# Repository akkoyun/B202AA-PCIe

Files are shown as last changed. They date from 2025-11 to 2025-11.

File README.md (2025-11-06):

# B202AA-PCIe  
### 3-Phase Energy Analyzer Module  
**Project:** PollyPhase Energy Analyzer  
**Author:** Mehmet Günce Akkoyun  
**Version:** 02.00.01  
**Date:** 06.11.2025  

---

## Overview  

**B202AA-PCIe** is a high-precision **three-phase energy analyzer module** designed for industrial and agricultural environments.  
The module is built around the **MAX78630+PPM/D00** poly-phase metering SoC and interfaces to the host system through a **custom PCIe-compatible connector**.  

It performs real-time measurement of:
- Line-to-neutral and line-to-line **voltages (VR, VS, VT)**  
- Phase currents via external **Current Transformers (CTs)**  
- Derived parameters such as **active/reactive/apparent power**, **energy (Wh)**, **power factor**, and **frequency**

The design focuses on:
- **High accuracy (Class 0.2S)** metering  
- **Complete galvanic isolation** for UART and alarm interfaces  
- **Wide input range and fault tolerance** for rugged field applications  

---

## Functional Blocks  

| Block | Function | Key Components |
|---|---|---|
| Voltage Input | Phase voltage scaling & isolation | 3×(3.3 M? + 1 k? divider, 22 nF filter, opto-isolator VOM617A) |
| Current Input | CT burden and protection | 3×(24.9 ? ± 0.1 % + 10 ? series, BAS316 clamps, 470 pF filter) |
| Measurement Core | 3-Phase metering | MAX78630+PPM/D00 |
| Isolation | UART & Alarm isolation | ISOW7821FDWE (UART), TLP2362 (AL1/AL2) |
| Power Isolation | 3.3 V - 3.3 V ISO DC/DC | PBT01F03S3V3 |
| Connector | Custom PCIe-style 52-pin edge | Compatible with all S-Bus PCIe modules |

---

## Measurement Inputs  

| Parameter | Nominal | Max (Continuous) | Description |
|---|---|---|---|
| Voltage (Phase–Neutral) | 230 V RMS | 400 V RMS | AC measurement via precision divider |
| Voltage (Phase–Phase) | 400 V RMS | 584 V RMS (safety) | Tested to 825 Vpk isolation |
| Current (CT input) | 5 A RMS nominal | 7 A RMS max | External CT, burden 24.9 ? + 10 ? |
| Frequency | 45 – 65 Hz | – | Automatic zero-cross detect |

---

## Electrical & Safety Specifications  

| Feature | Value / Description |
|---|---|
| **Galvanic Isolation** | ? 6 mm creepage/clearance (IPC9592 compliant) |
| **UART Isolation Voltage** | 2500 Vrms (ISOW7821) |
| **Alarm Isolation Voltage** | 3750 Vrms (TLP2362) |
| **TVS Protection** | 440 V (SMAJ440A) per phase |
| **Operating Temperature** | –25 °C to +85 °C |
| **Supply Voltage** | 3.3 V / 3.3 V ISO |
| **Power Consumption** | ? 0.8 W total |

---

## Accuracy & Error Budget  

### Voltage Channel (per phase)
| Item | Value | Note |
|---|---|---|
| Divider ratio | 3.3 M? : 1 k? | 0.1 % tolerance |
| Gain error (uncalibrated) | ±0.20 % | RSS of divider & ADC |
| Phase error (50 Hz) | –0.40° | From 22 nF filter |
| Gain drift (0–70 °C) | ±0.18 % | Typical |
| After calibration | ±0.05 % gain / ±0.05° phase | with 2-point + phase comp |

### Current Channel (per phase)
| Item | Value | Note |
|---|---|---|
| Burden | 24.9 ? ± 0.1 % + 10 ? | Kelvin connection |
| Gain error (uncalibrated) | ±0.20 % | ADC + burden |
| CT class impact | ±0.2 % – ±1.0 % | per CT rating |
| After calibration | ±0.10 – 0.20 % | typical |

### Combined Power (Active Power Error)
| Condition | PF = 1.0 | PF = 0.9 | PF = 0.5 |
|---|---|---|---|
| Uncalibrated (CT = 0.5 %) | ±0.58 % | ±0.67 % | ±1.34 % |
| Calibrated | ±0.10 – 0.20 % | ±0.15 – 0.25 % | ±0.20 – 0.35 % |

**Energy (Wh) Accuracy:**  
Limited by power error + timebase tolerance (20 MHz ± 50 ppm).  
Resulting energy error typically **< ±0.25 % over 24 h** integration.

---

## Safety Margin Calculations  

### Voltage Divider  
- Total resistance: 3.301 M?  
- At 230 Vac: I ? 0.32 mA › P_total = 0.073 W  
- At 400 Vac: I ? 0.56 mA › P_total = 0.22 W  
- Per resistor (180 k?): ? 56 mW / 0.5 W = 11 % load  
- Temperature rise ? +14 °C › **safe below 74 °C**

### CT Burden Protection  
- Normal V_burden ? 0.25 Vpk (5 A RMS)  
- Clamp limit ? ±0.7 V › 3× margin  
- Diodes conduct only under fault, ensuring **no influence on phase**.

### Isolation  
- Creepage/clearance: ? 6 mm  
- TVS breakdown: 440 V pk  
- Withstand: 2.5 kVrms (UART) / 3.75 kVrms (Alarm)  

---

## Performance Summary  

| Parameter | Result |
|---|---|
| Voltage Accuracy | ±0.05 % (calibrated) |
| Current Accuracy | ±0.10 – 0.20 % (CT dependent) |
| Active Power Accuracy | ±0.20 – 0.35 % (typical PF range) |
| Energy Accuracy | ±0.25 % / day |
| Phase Drift | ? 0.05° (after compensation) |
| Temperature Coefficient | < 0.02 % / °C |
| Safety Margin (400 V RMS) | +45 % |

---

## Subsystem Scores  

| Subsystem | Score (10) | Notes |
|---|---|---|
| Phase Sense / Opto Isolation | **9.5** | Excellent thermal and fault safety |
| Voltage Divider & Filter | **9.0** | Very accurate; phase comp suggested |
| CT Channel & Protection | **9.5** | Ideal burden use, safe clamp |
| UART Isolation | **9.0** | Layout decoupling critical |
| Alarm Isolation | **9.0** | LED logic verified, add 100 ? ESD resistor |
| MAX78630 Core Integration | **9.5** | Datasheet-accurate, stable design |
| Power & EMC Architecture | **9.0** | Add CMC for field noise immunity |
| Connector & System Integration | **9.0** | Solid mechanical & logical design |

**Overall Design Score:** ? **9.2 / 10**

---

## Calibration & Testing  

**Recommended Calibration Steps:**  
1. Two-point voltage and current gain calibration (0.5 FS & FS).  
2. Phase compensation per channel at 50 Hz reference.  
3. Optional temperature drift mapping (25 °C / 50 °C / 70 °C).  
4. Verify PF = 1.0 and PF = 0.5 energy accumulation error.  

**Expected Post-Calibration Class:**  
- **Class 0.2 / 0.2S** accuracy (EN 62053-22 compliant).

---

## Licensing & Documentation  

© 2025 Günce Akkoyun – All Rights Reserved  
Design and documentation by **Mehmet Günce Akkoyun**  
Commercial use without permission is prohibited.  

**Repository:** [github.com/akkoyun/B202AA-PCIe](https://github.com/akkoyun/B202AA-PCIe)  
**Contact:** akkoyun@me.com  

---

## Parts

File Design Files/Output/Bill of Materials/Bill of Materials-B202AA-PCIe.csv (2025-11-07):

ROHS | Designator | Manufacturer Name | Manufacturer Part Number | Quantity | Case | Description | Max Input Voltage | Max Operating Temperature | Tolerance | Value | Product Type
 | C1, C4, C11, C14, C21, C22, C23, C25, C26 | AVX, KYOCERA AVX | 04026D104KAT4A | 9 | 0402 | Capacitor - 100nF [0402-6V3] (Ceramic), Capacitor (MLCC) - 100nF / 6V3 / 0402 |  |  | %10 | 100nF
 | C2, C5, C24, C27 | Murata Electronics | GRM153R60J105ME95D | 4 | 0402 | Capacitor (MLCC) - 1uF / 6V3 / 0402 |  |  | 20% | 1uF
 | C3, C6 | KYOCERA AVX | 04026D473KAT2A | 2 | 0402 | Capacitor (MLCC) - 47nF / 6V3 / 0402 |  |  | 10% | 47nF
 | C7, C8, C9 | Murata | GRM1885C1H471JA01 | 3 | 0603 | Capacitor (MLCC) - 470pF / 50V / 0603 |  |  | 5% | 470pF
 | C10 | Murata Electronics | GCJ188R71E105KA01D | 1 | 0603 | Capacitor (MLCC) - 1uF / 25V / 0603 |  |  | 10% | 1uF
 | C12, C13 | KYOCERA AVX | 04025A8R0CAT2A | 2 | 0402 | Capacitor - 8pF [0402] (Ceramic) |  |  | 0.25pF | 8pF
 | C15, C16, C17 | Yageo | C0805C223K5RACTU | 3 | 0805 | Capacitor (MLCC) - 22nF / 50V / 0805 |  |  | 10% | 22nF
 | C18, C19, C20 | Murata | GRM155R71H102KA01D | 3 | 0402 | Capacitor (MLCC) - 1nF / 50V / 0402 |  |  | 10% | 1nF
 | C28 | KEMET | C0402C475M9PACTU | 1 | 0402 | Multilayer Ceramic Capacitors - SMD - 6V3 4.7uF X5R 0402 20% |  |  | 20% | 4.7uF
 | C29 | Wurth Elektronik | 885012207024 | 1 | 0805 | Multilayer Ceramic Capacitors MLCC - SMD/SMT WCAP-CSGP 2.2uF 0805 10% 10V MLCC |  |  | 10% | 2.2uF
Yes | D1, D2, D9, D13, D17 | ROHM Semiconductor | SML-P12VTT86R | 5 | 0402 | Standard LEDs - SMD MINI-MOLD ULTRA COMPACT RED
Yes | D3, D4, D5, D6, D7, D8 | Panjit | BAS316_R1 | 6 | SOD-323-2 | Small Signal Switching Diodes 100V,Small Signal Switching Diodes,SOD-323,4A |  |  |  |  | Small Signal Switching Diodes
Yes | D10, D12, D14 | Nexperia | BZT52H-B5V1,115 | 3 | SOD-123F-2 | Zener Diodes BZT52H-B5V1/SOD123F/SOD2 |  |  |  |  | Zener Diodes
Yes | D11, D15, D19 | Bourns | SMAJ440A | 3 | DO-214AC-2 | ESD Protection Diodes / TVS Diodes 440volts 1uA .6 Amps Uni-Dir |  |  |  |  | TVS Diodes
 | FB1 | Murata Electronics | BLM18EG101TZ1D | 1 | 0603 | Ferrite Beads 0603 100ohms 2000mA Auto Infotainment |  |  | 25% | BLM18EG101TZ1D
 | J2 | Molex | 53426-0710 | 1 | TH | 2.50mm Pitch Mini-Lock Wire-to-Board Header Right Angle Friction and Positive Lock 7 Circuits
Yes | J3 | Molex | 53261-0671 | 1 |  | Mini Tunic Connector with 6P
 | R1, R4, R49, R55, R61 | Vishay | CRCW04024K70FKED | 5 | 0402 | Thick Film Resistors - SMD 1/16 W 4.7 KOhm 1% |  |  | %1 | 4K7
 | R2, R5 | Vishay | CRCW04021K80FKED | 2 | 0402 | Thick Film Resistors - SMD 1/16 W 1.8 KOhm 1% |  |  | %1 | 1K8
 | R3, R6 | Vishay | CRCW040247R0FKED | 2 | 0402 | Thick Film Resistors - SMD 1/16 W 47 Ohm 1% |  |  | %1 | 47R
 | R7, R10, R13 | Yageo | RT0805BRD0710RL | 3 | 0805 | Thick Film Resistors - SMD 1/8 W 10 Ohm 0.1% |  |  | %0.1 | 10R
 | R8, R11, R14 | Yageo | RT1206BRD0724R9L | 3 | 1206 | Burden Resistors - SMD 1/4 W 24.9 Ohm 0.1% |  |  | 0.1% | 24R9
 | R9, R12, R15, R30 | Vishay | CRCW04020000Z0ED | 4 | 0402 | Thick Film Resistors - SMD 1/16 W 0 Ohm |  |  |  | 0R
 | R16, R17, R18, R19, R20, R21, R33, R75 | Vishay | CRCW040210K0FKED | 8 | 0402 | Thick Film Resistors - SMD 1/16 W 10 KOhm 1% |  |  | %1 | 10K
 | R22, R24, R26, R27, R28, R29, R31, R32, R67, R68, R69, R70 | Vishay | CRCW040247K0FKED | 12 | 0402 | Thick Film Resistors - SMD 1/16 W 47 KOhm 1% |  |  | %1 | 47K
 | R23, R25, R71, R72, R73, R74 | Vishay | CRCW040233R0FKED | 6 | 0402 | Thick Film Resistors - SMD 1/16 W 33 Ohm 1% |  |  | %1 | 33R
 | R34, R35, R36, R38, R39, R40, R42, R43, R44 | Yageo | RT1206BRD071M1L | 9 | 1206 | Thick Film Resistors - SMD 1/4 W 1.1 MOhm 0.1% |  |  | %0.1 | 1M1
 | R37, R41, R45 | Vishay | CRCW0805100RFKEA | 3 | 0805 | Thick Film Resistors - SMD 1/4 W 100 Ohm 1% |  |  | %1 | 100R
 | R46, R47, R48 | Panasonic | ERA-6AEB102V | 3 | 0805 | Thick Film Resistors - SMD 1/8 W 1 KOhm 0.1% |  |  | %0.1 | 1K
 | R50, R56, R62 | Vishay | CRCW0402100KFKED | 3 | 0402 | Thick Film Resistors - SMD 1/16 W 100 KOhm 1% |  |  | %1 | 100K
 | R51, R52, R53, R54, R57, R58, R59, R60, R63, R64, R65, R66 | Panasonic | ERJ-P06D1803V | 12 | 0805 | Thick Film Resistors - SMD 0805 180Kohms 0.5W 0.5% AEC-Q200 |  |  | %0.5 | 180K
 | U1, U2 | Toshiba | TLP2362(TPR,E | 2 | SMD | High Speed Optocouplers 3750 Vrms 10MBd 4mA 2.7 to 5.5V LED
Yes | U3 | Silergy | MAX78630+PPM/D00 | 1 | TQFN-32 | Energy Measurement Processor 32-Pin TQFN EP Tube
Yes | U4, U5, U6 | Vishay | VOM617A-4T | 3 | SOP-4 | Transistor Output Optocouplers Phototransistor Out CTR 160-320% 5mA |  |  |  |  | Transistor Output Optocouplers
 | U7 | Texas Instruments | ISOW7821FDWE | 1 | SOIC-16 | Digital Isolators Dual-channel 1/1 r einforced digital is A 595-ISOW7821FDWER
 | U8, U9, U10 | OnSemi | MB10S | 3 | SOIC-4 | Transistor Output Optocouplers Optocplr Phototrans 4-Channel
 | X1 | Kyocera Electronic Components | CX2016DB20000D0GPSC1 | 1 | SMD | Crystals AEC-Q200 20000kHz 8pF 2x1.6mm

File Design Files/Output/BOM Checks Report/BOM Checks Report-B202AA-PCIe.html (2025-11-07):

Date: |  | 7.11.2025
Time: |  | 15:56
Elapsed Time: |  | 00:00:00
Filename: |  | C:\Users\akkoyun\Documents\B202AA-PCIe\Design Files\B202AA-PCIe.BomDoc
Warnings: |  | 14
Errors: |  | 0
Fatal Errors: |  | 135
Warnings: | Count
Value '100nF' is duplicate | 9
Value '1uF' is duplicate | 5
Total | 14
Errors: | Count
Total | 0
Fatal Errors: | Count
No solutions | 135
Total | 135
Value '100nF' is duplicate
C1 , C4, C11, C14, C21, C22, C23, C25, C26
Value '1uF' is duplicate
C2 , C5, C10, C24, C27
No solutions
C1 , C2, C3, C4, C5, C6, C7, C8, C9, C10, C11, C12, C13, C14, C15, C16, C17, C18, C19, C20, C21, C22, C23, C24, C25, C26, C27, C28, C29, D1, D2, D3, D4, D5, D6, D7, D8, D9, D10, D11, D12, D13, D14, D15, D17, D19, FB1, J2, J3, R1, R2, R3, R4, R5, R6, R7, R8, R9, R10, R11, R12, R13, R14, R15, R16, R17, R18, R19, R20, R21, R22, R23, R24, R25, R26, R27, R28, R29, R30, R31, R32, R33, R34, R35, R36, R37, R38, R39, R40, R41, R42, R43, R44, R45, R46, R47, R48, R49, R50, R51, R52, R53, R54, R55, R56, R57, R58, R59, R60, R61, R62, R63, R64, R65, R66, R67, R68, R69, R70, R71, R72, R73, R74, R75, U1, U2, U3, U4, U5, U6, U7, U8, U9, U10, X1

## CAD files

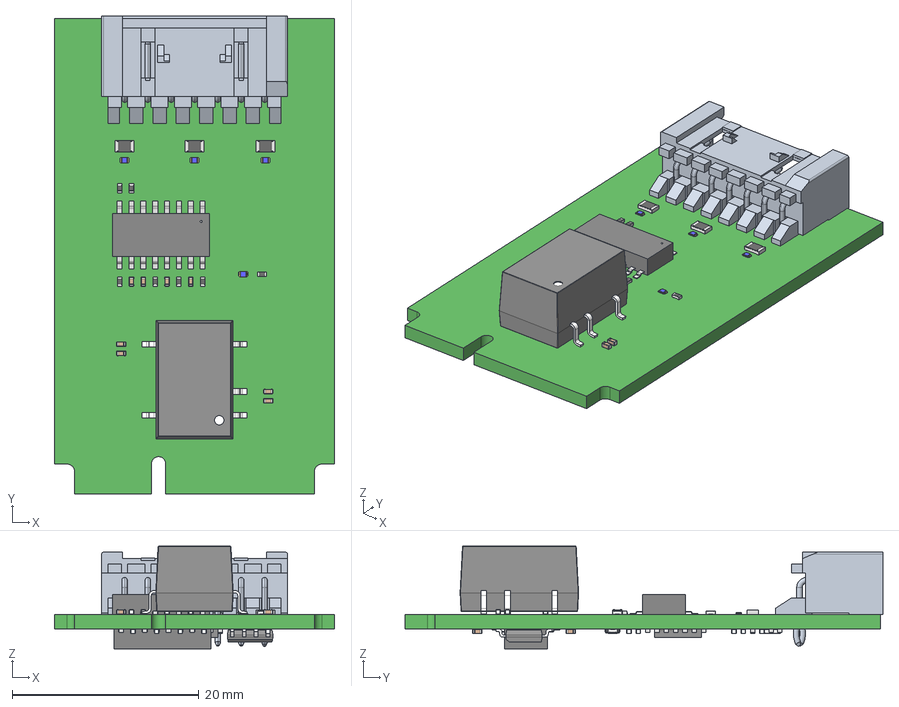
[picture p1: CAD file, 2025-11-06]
Design Files/Output/Export STEP/B202AA-PCIe.step
30.0 x 51.2 x 11.0 mm
SOP-16_TCMT_VIS x 2
0805CRCW x 6
0402CRCW x 42
User Library-LED_1006_B_Cut006 x 4
User Library-LED_1006_B_Cut005 x 4
User Library-LED_1006_B_Cut005_(Mirror_#1) x 4
User Library-LED_1006_B_Pad001 x 4
User Library-LED_1006_G_Gruen x 4
0402CAPMLCC x 33
ACIS Solid_1923
ACIS Solid_1935
SO8 Narrow 3.9mm x 9
QFN32 5x5
PDS1-S3-S3-M

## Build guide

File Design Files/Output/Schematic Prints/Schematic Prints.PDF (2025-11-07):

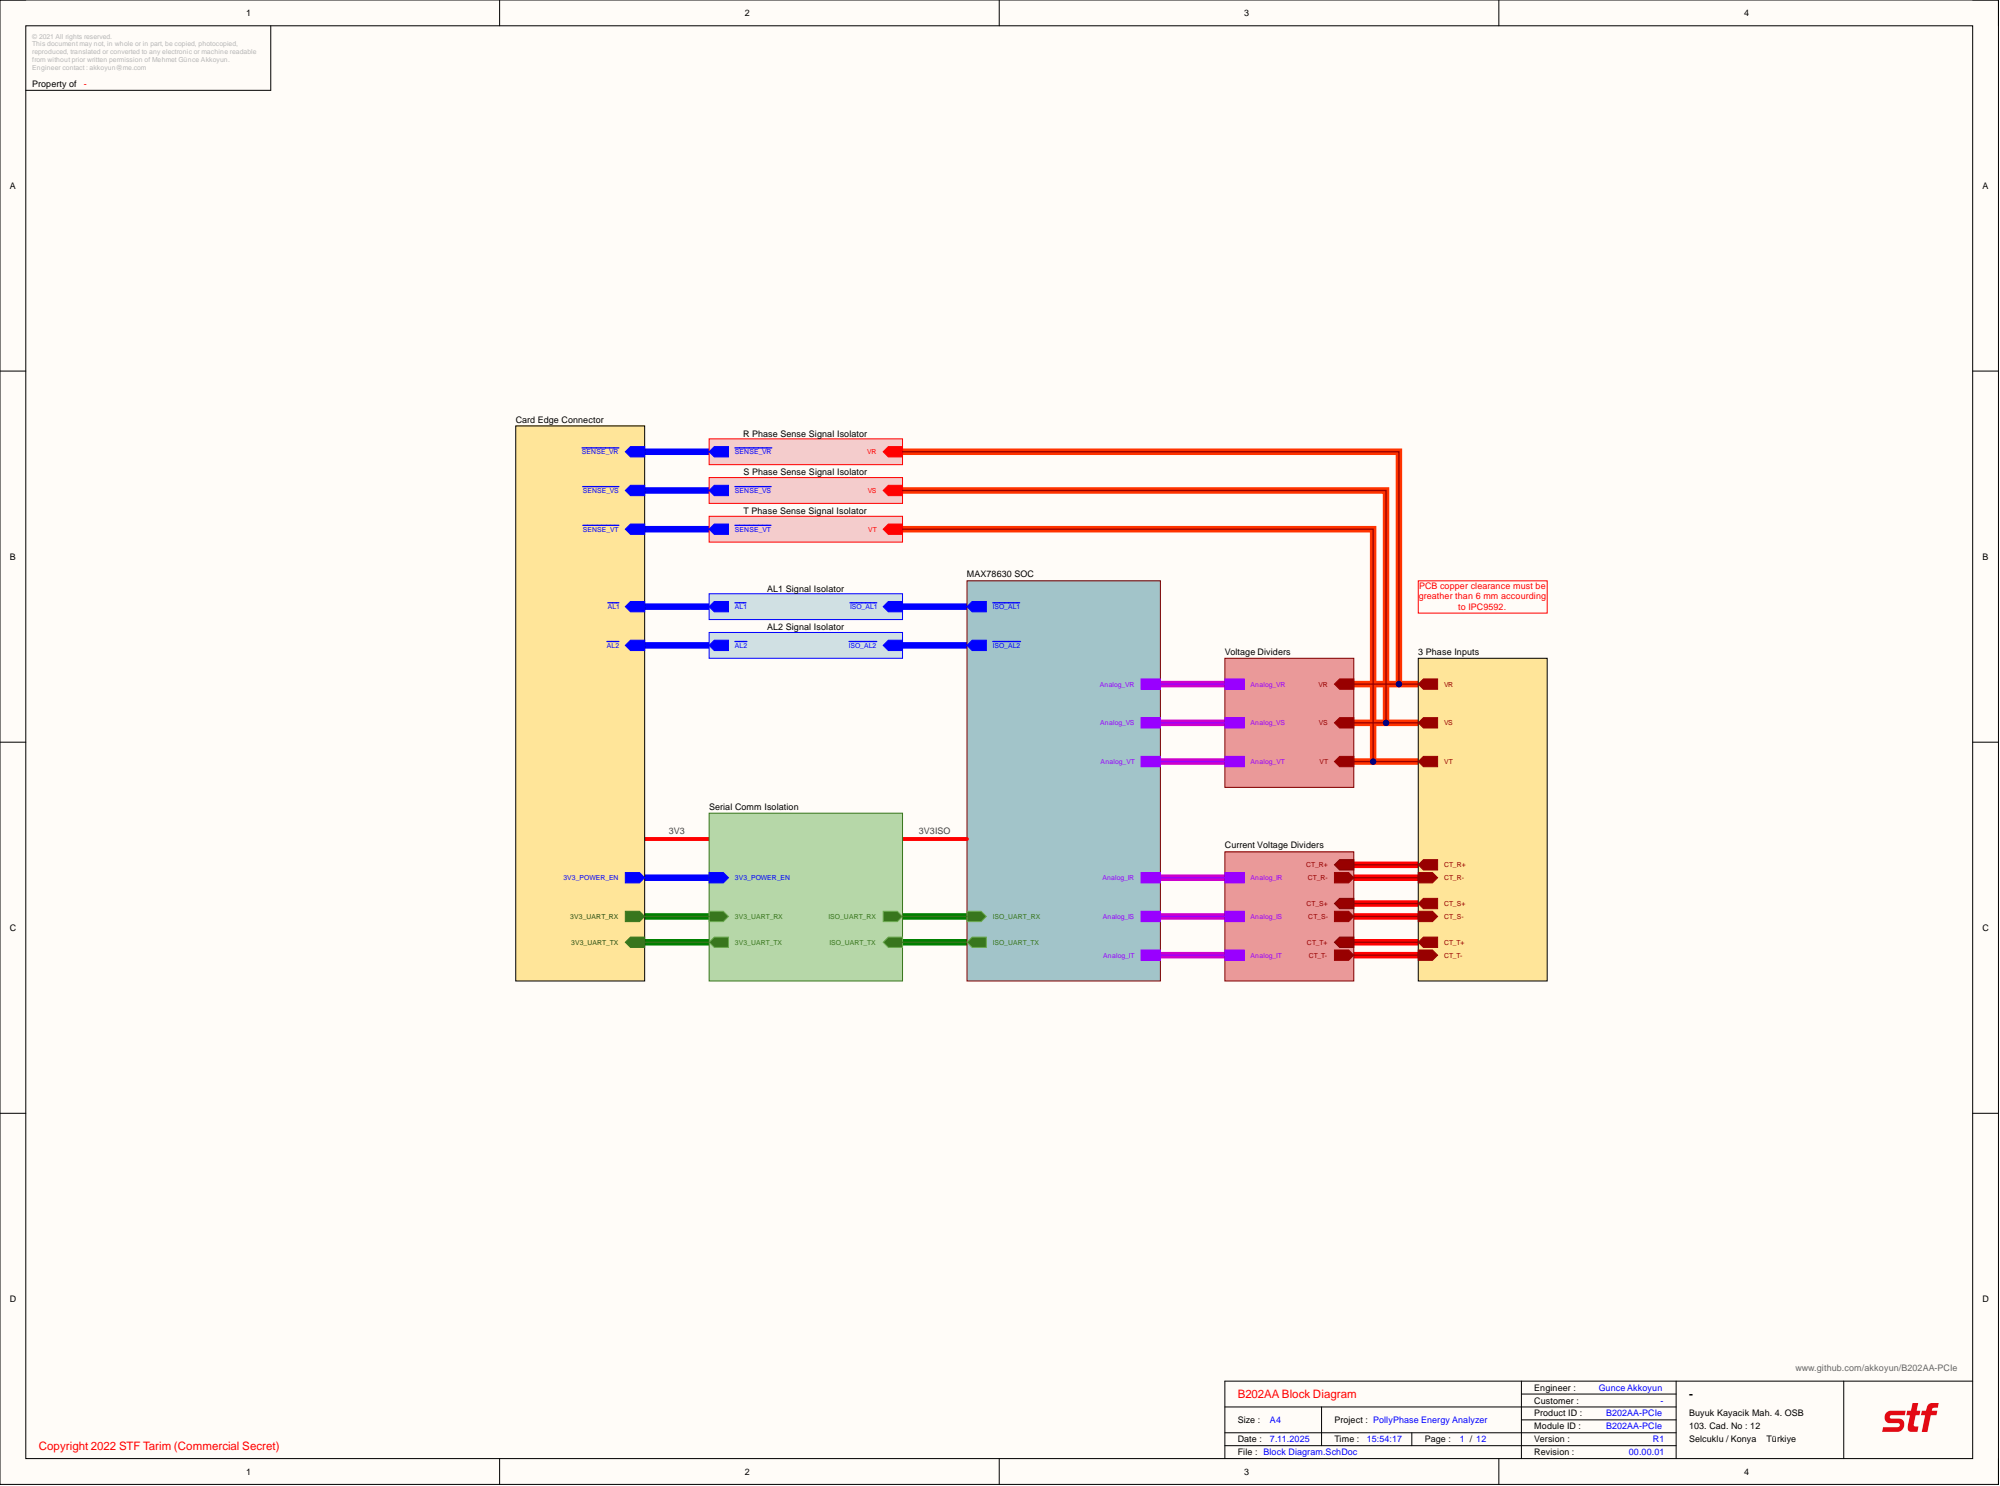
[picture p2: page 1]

© 2021 All rights reserved.
This document may not, in whole or in part, be copied, photocopied,
reproduced, translated or converted to any electronic or machine readable
from without prior written permission of Mehmet Günce Akkoyun.
Engineer contact : akkoyun@me.com

R Phase Sense Signal Isolator

S Phase Sense Signal Isolator

T Phase Sense Signal Isolator

PCB copper clearance must be
greather than 6 mm accourding

ISO_UART_TX

www.github.com/akkoyun/B202AA-PCIe

Buyuk Kayacik Mah. 4. OSB
103. Cad. No : 12
Selcuklu / Konya Türkiye

Copyright 2022 STF Tarim (Commercial Secret)

File : Block Diagram.SchDoc

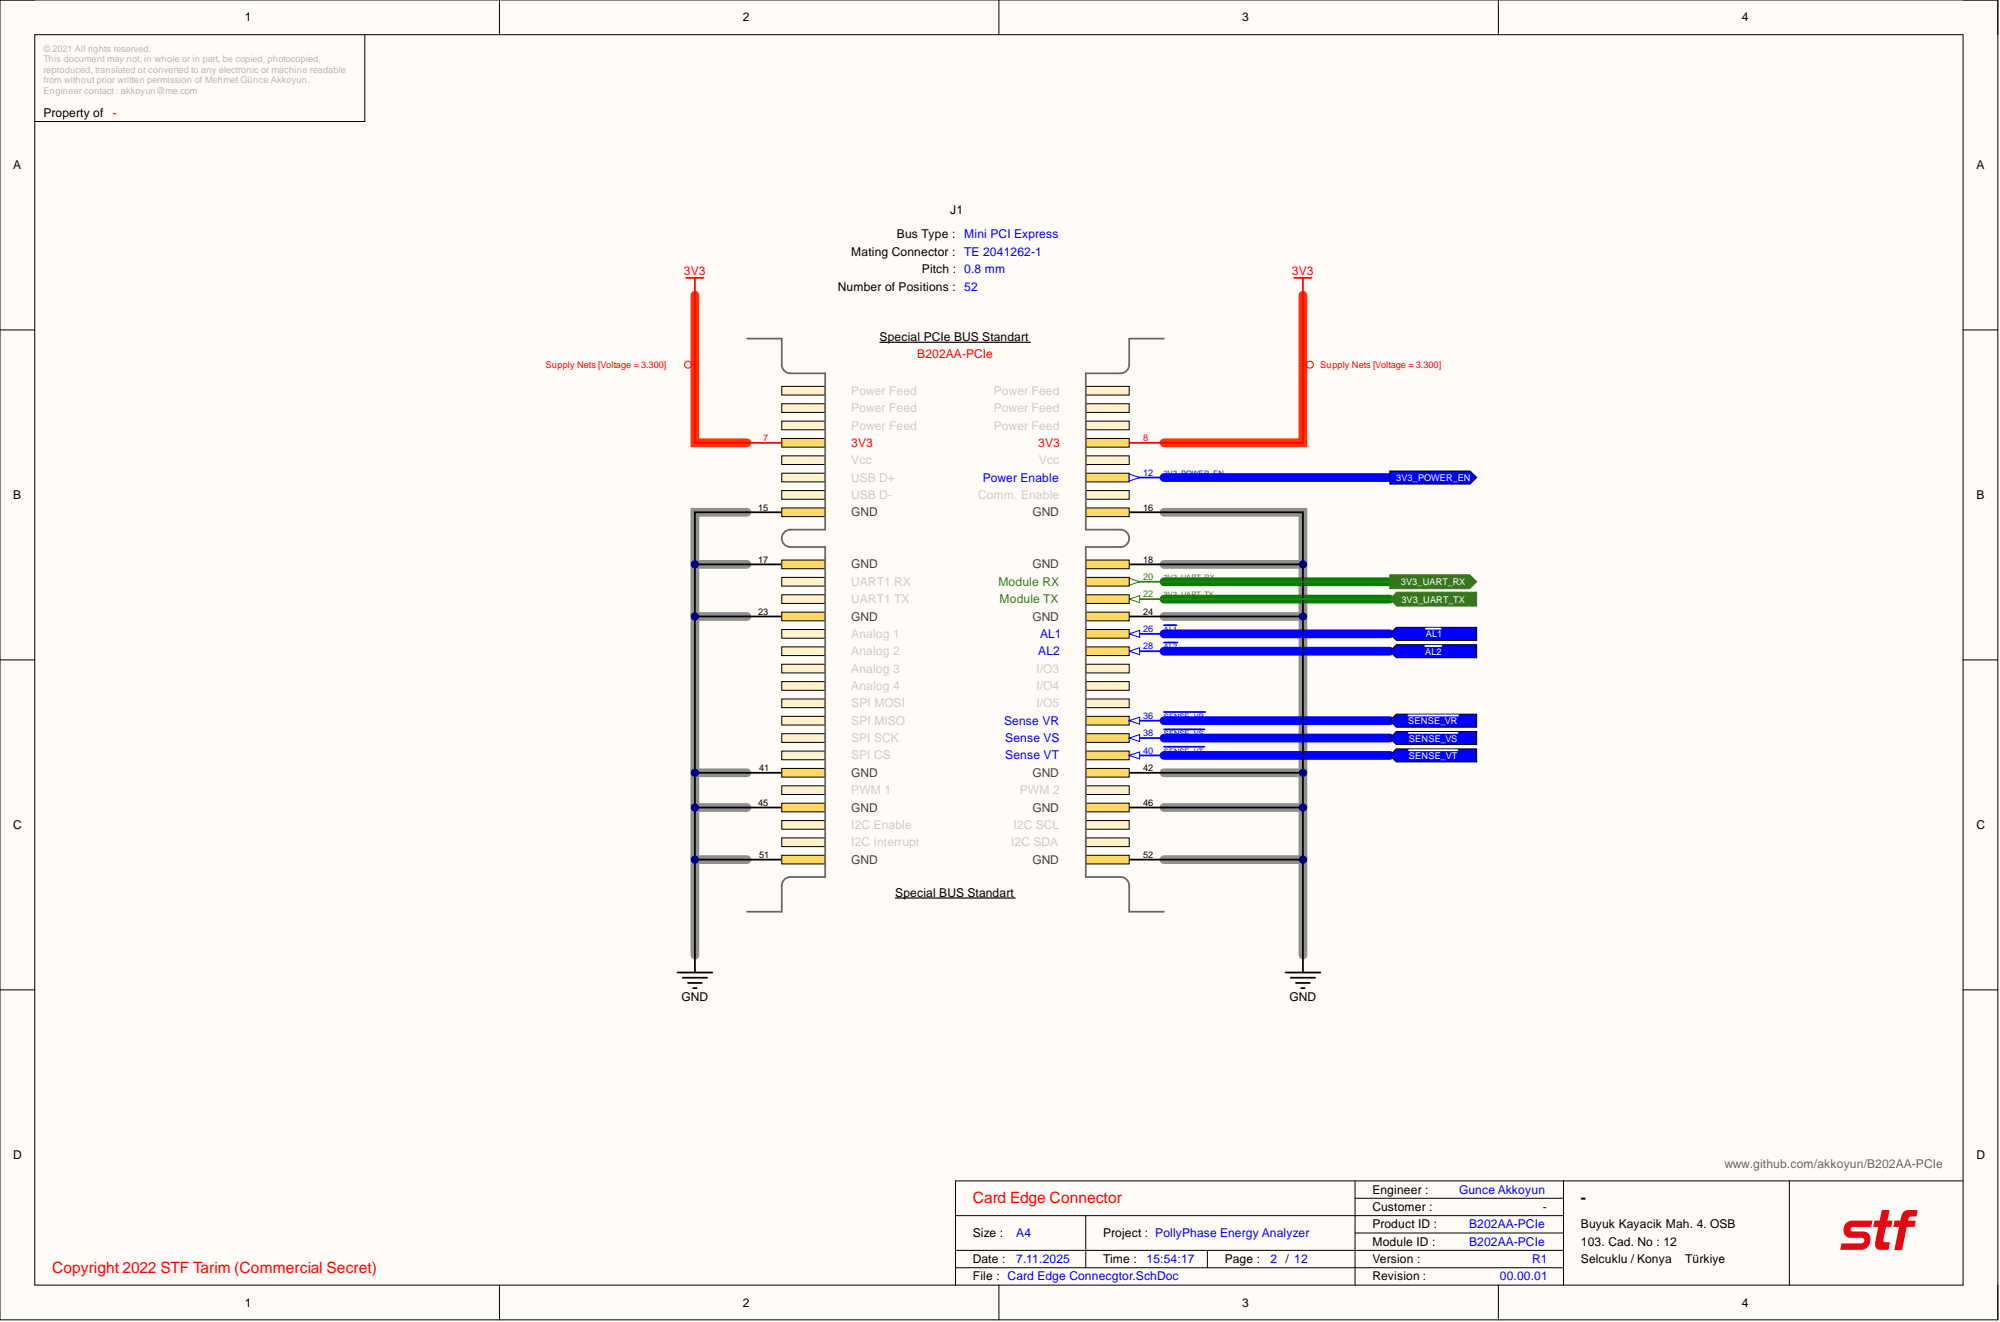
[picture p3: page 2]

Special PCIe BUS Standart

www.github.com/akkoyun/B202AA-PCIe

File : Card Edge Connecgtor.SchDoc

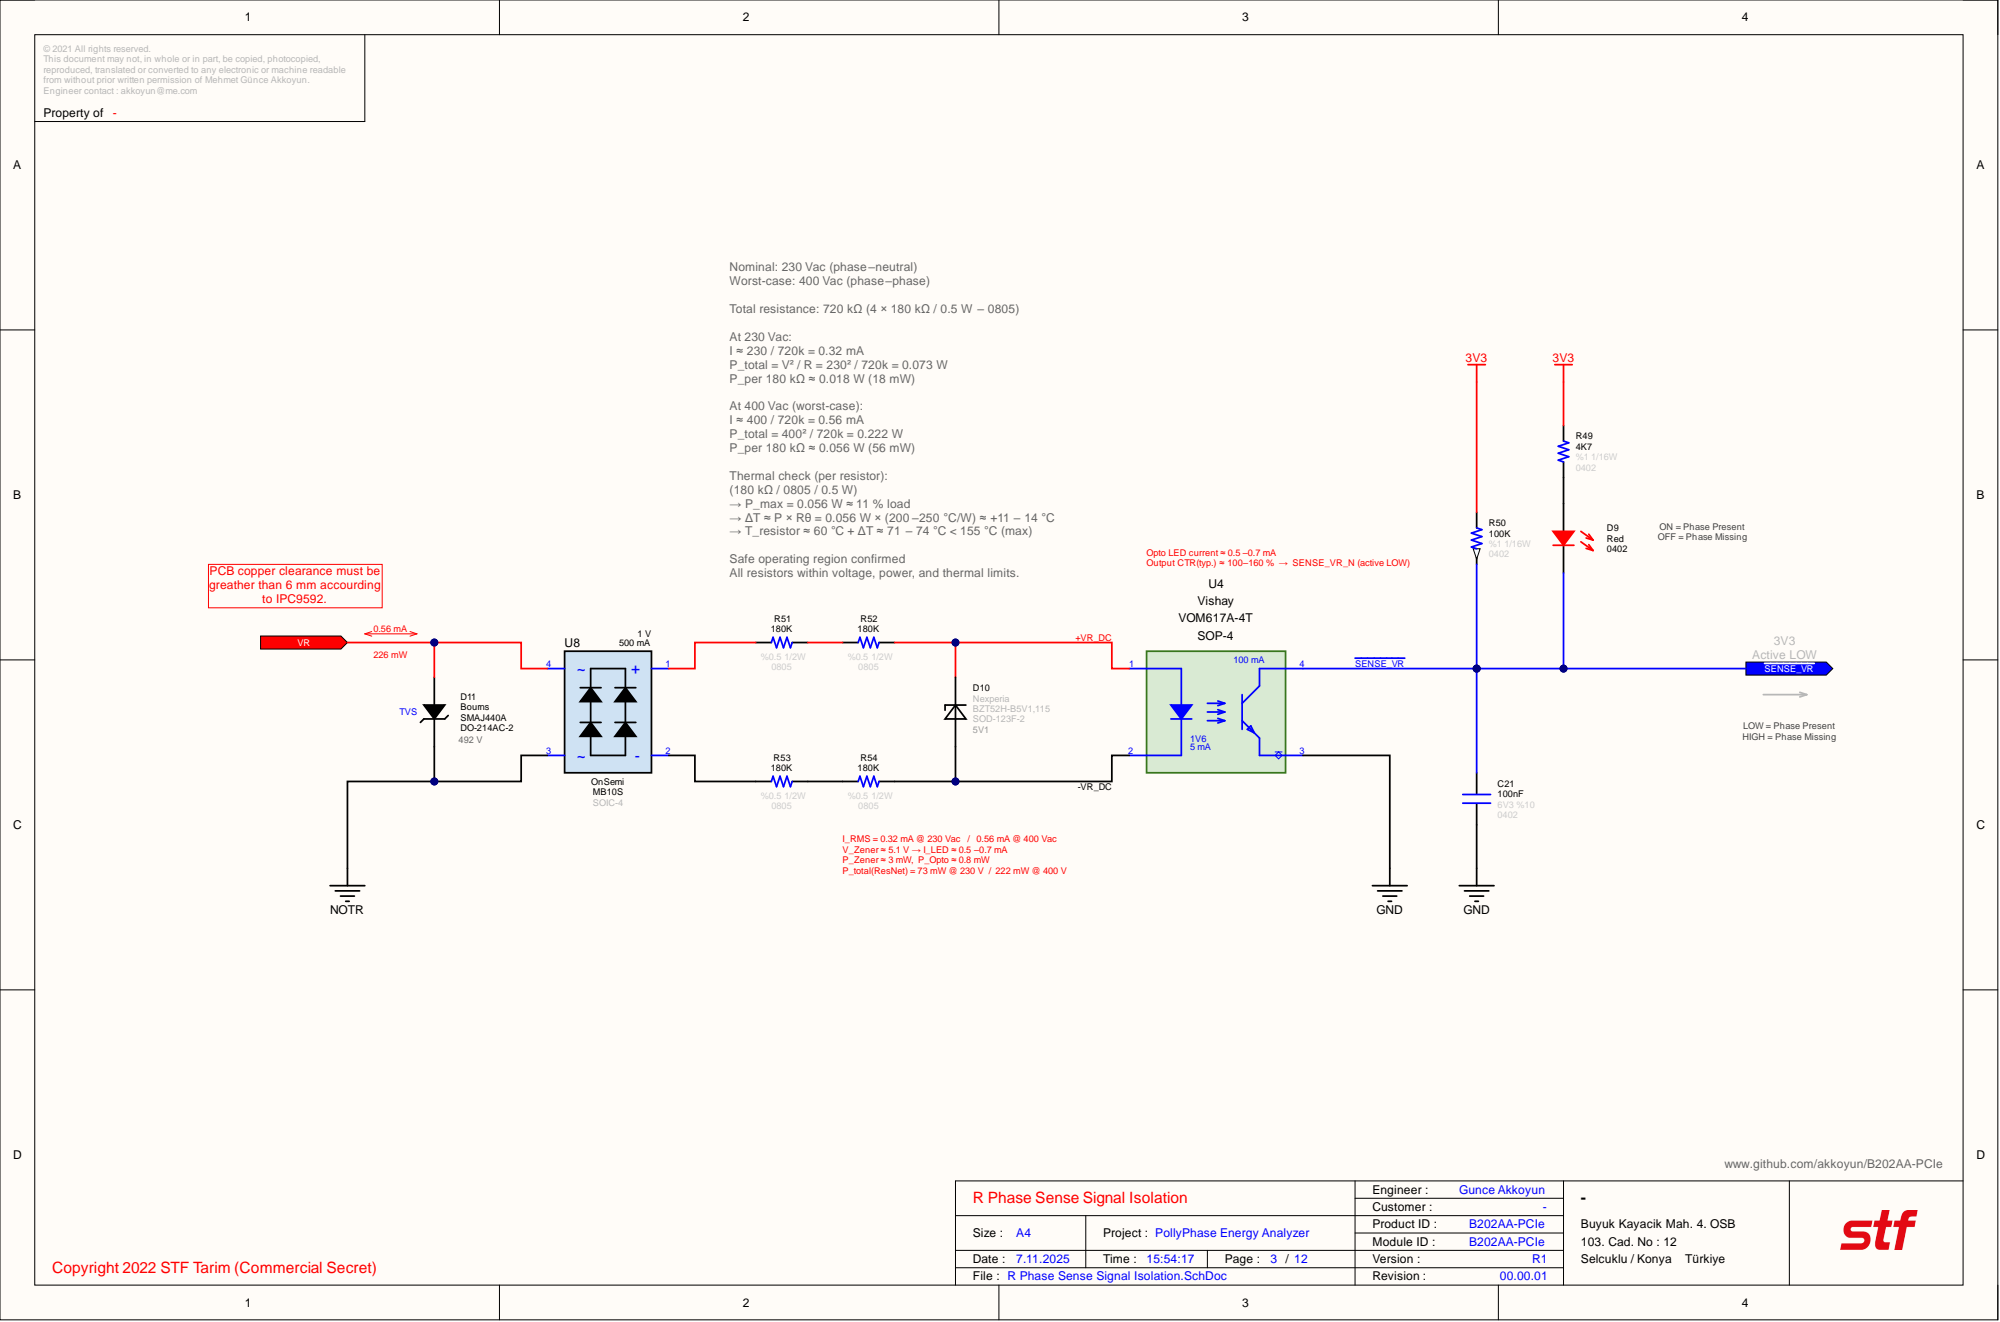
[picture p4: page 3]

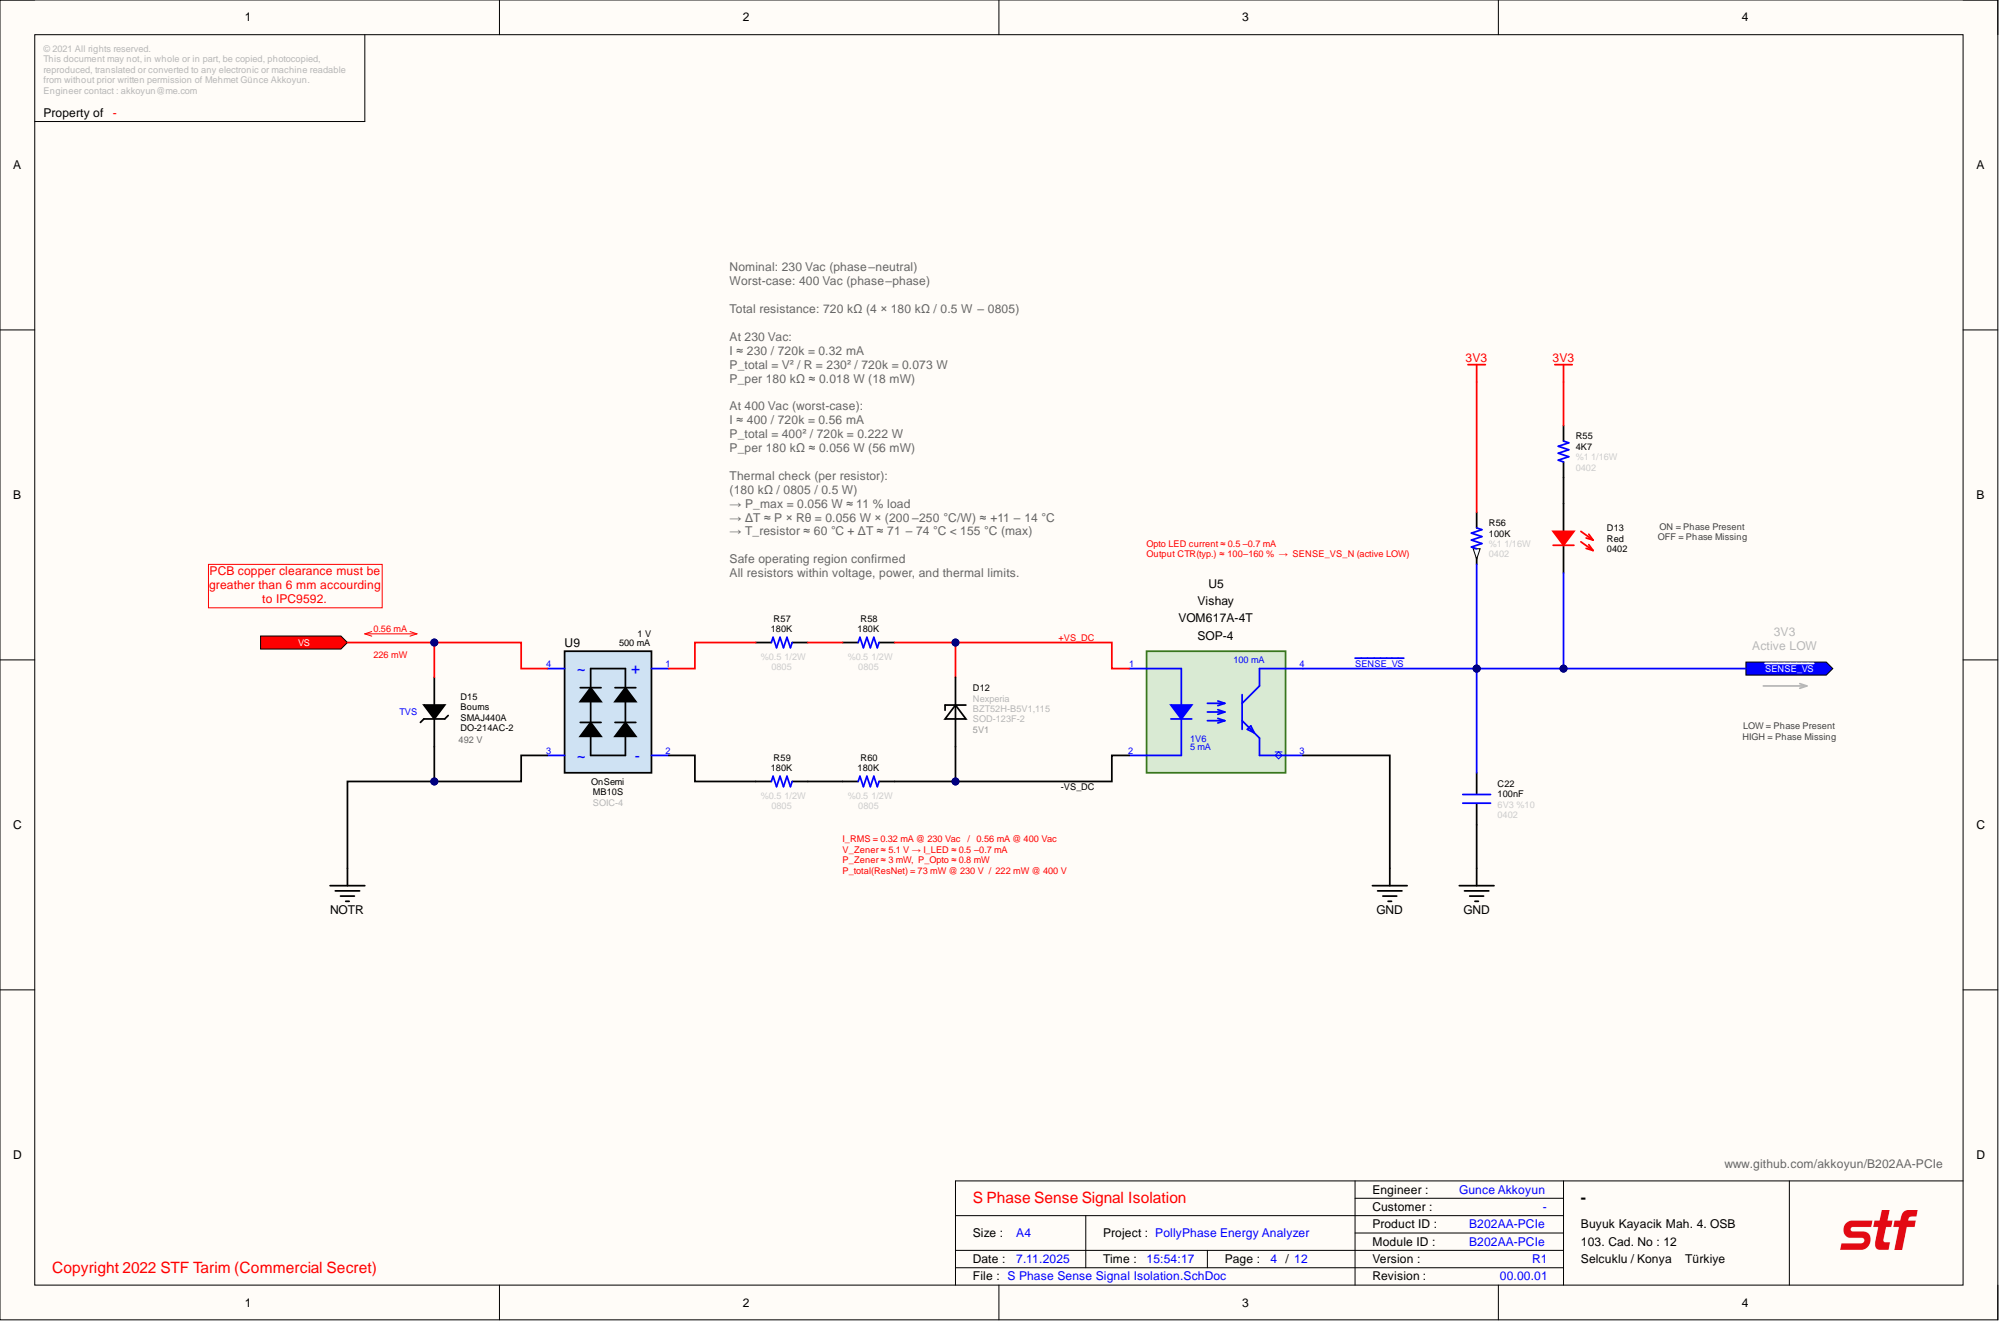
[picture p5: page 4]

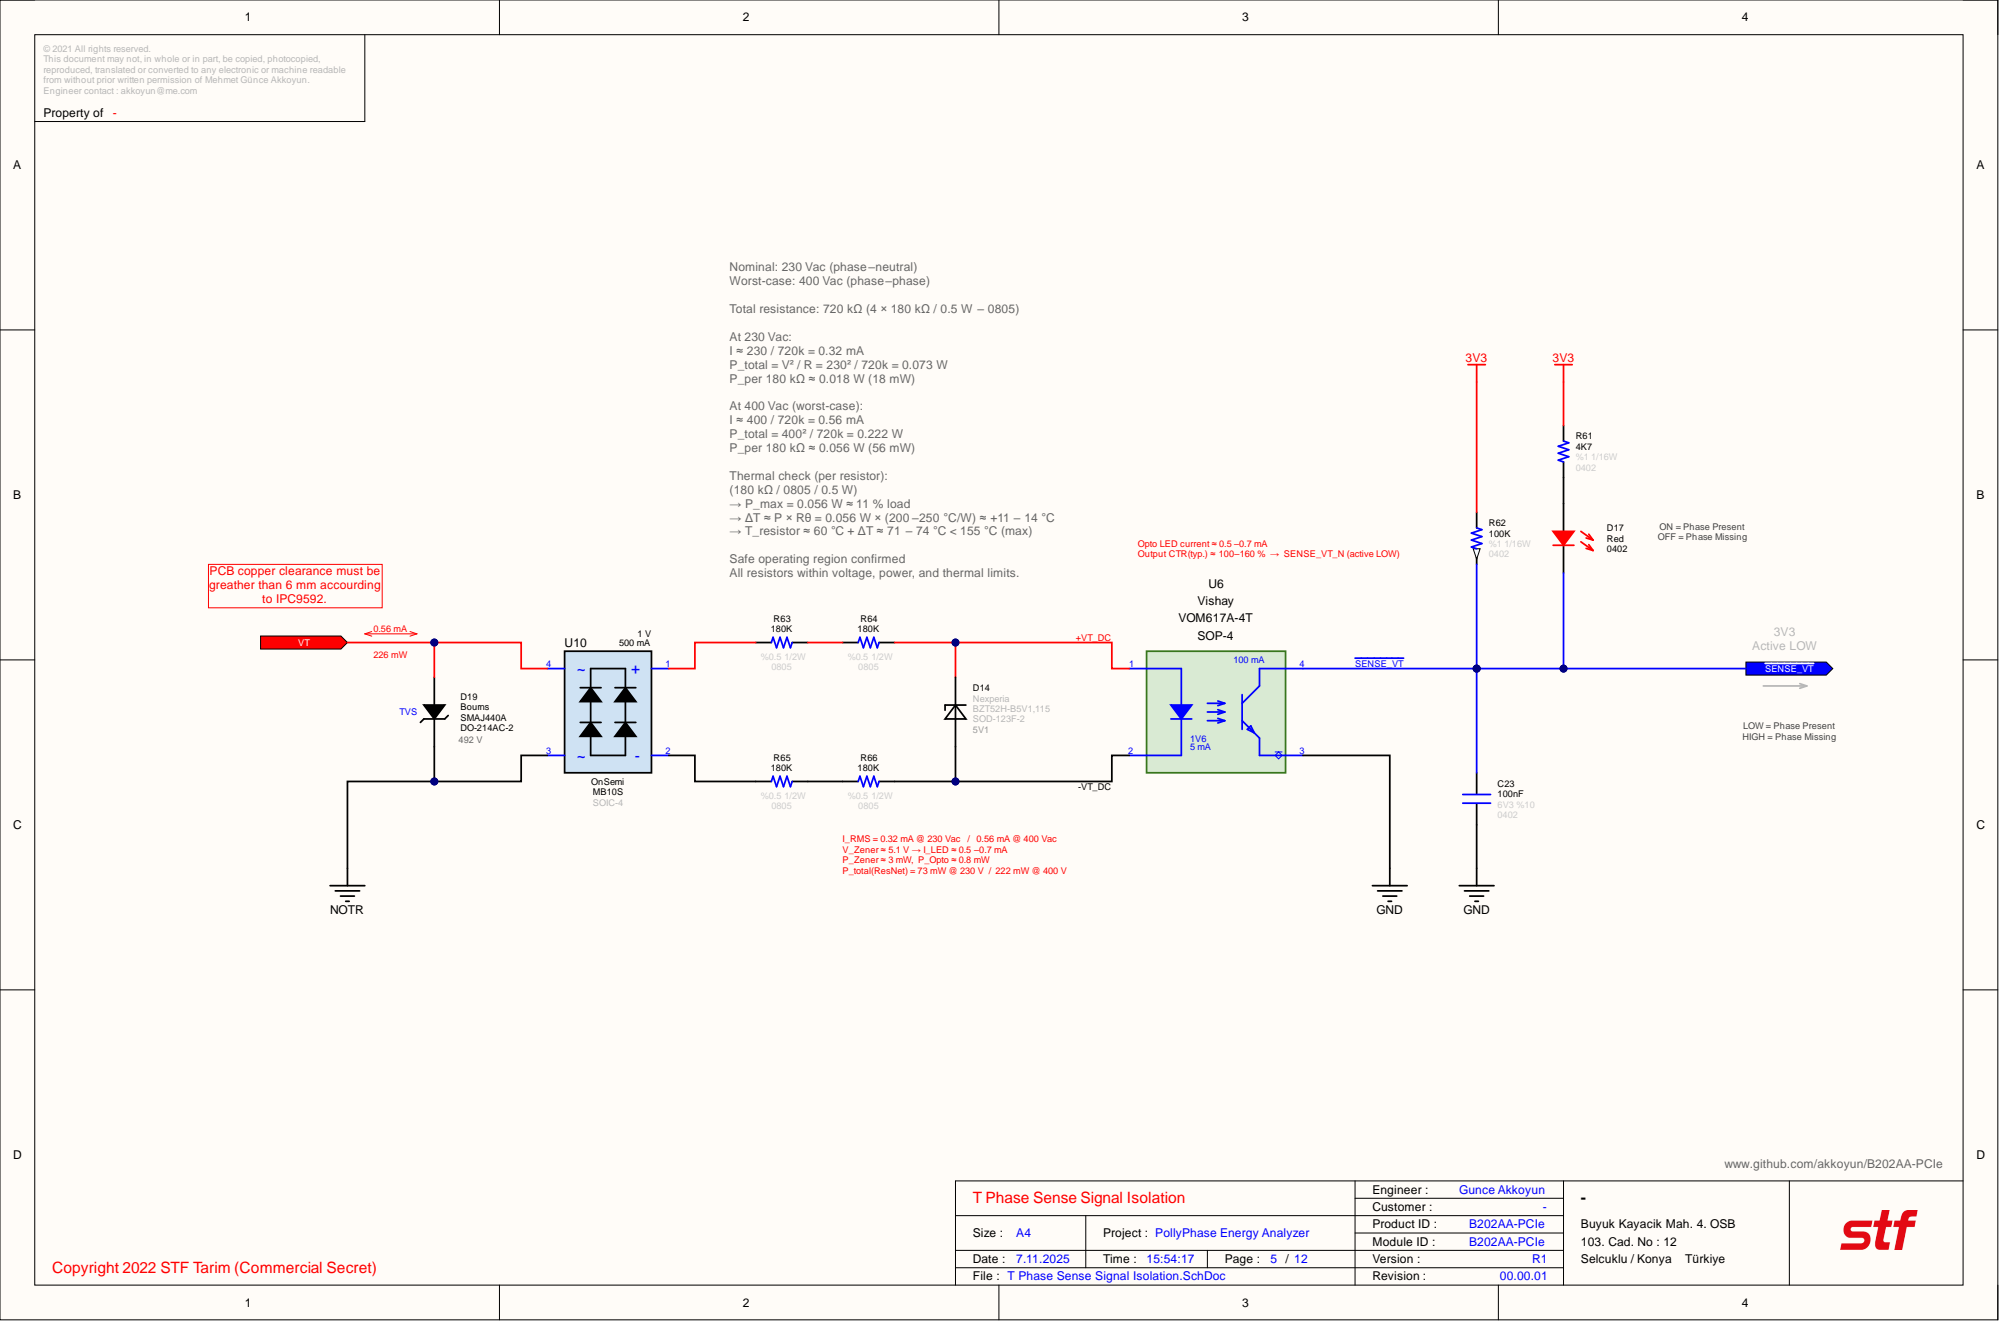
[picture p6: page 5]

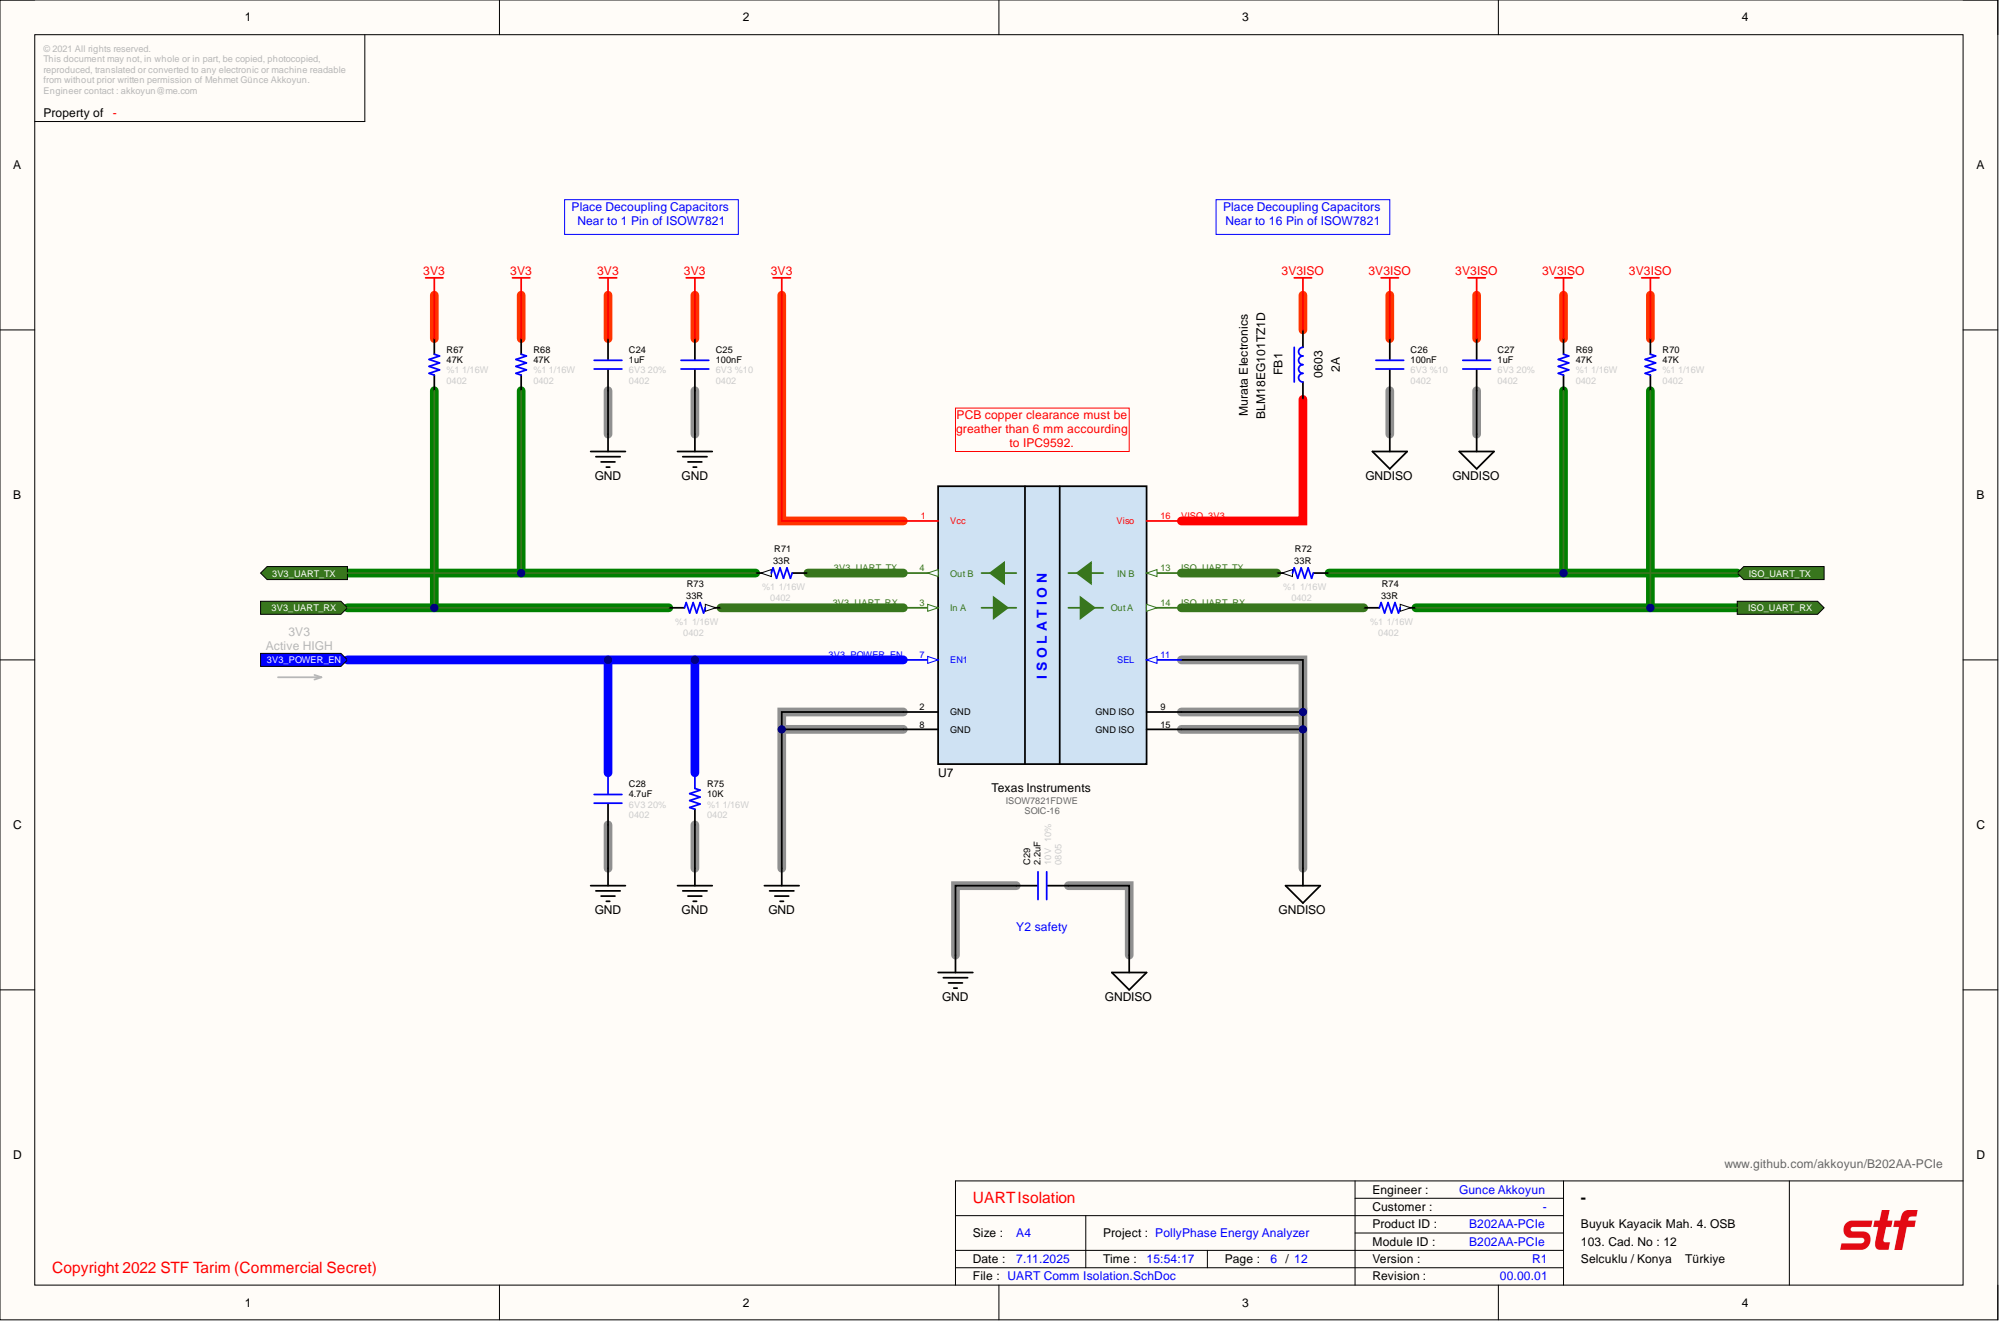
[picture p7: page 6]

Place Decoupling Capacitors
Near to 1 Pin of ISOW7821

Near to 16 Pin of ISOW7821

PCB copper clearance must be
greather than 6 mm accourding

Vcc 1 | GND ISO

Out B 4 In A 3 EN1 7 GND 2 | | ISO_UART_TX_

GND 8

www.github.com/akkoyun/B202AA-PCIe

File : UART Comm Isolation.SchDoc

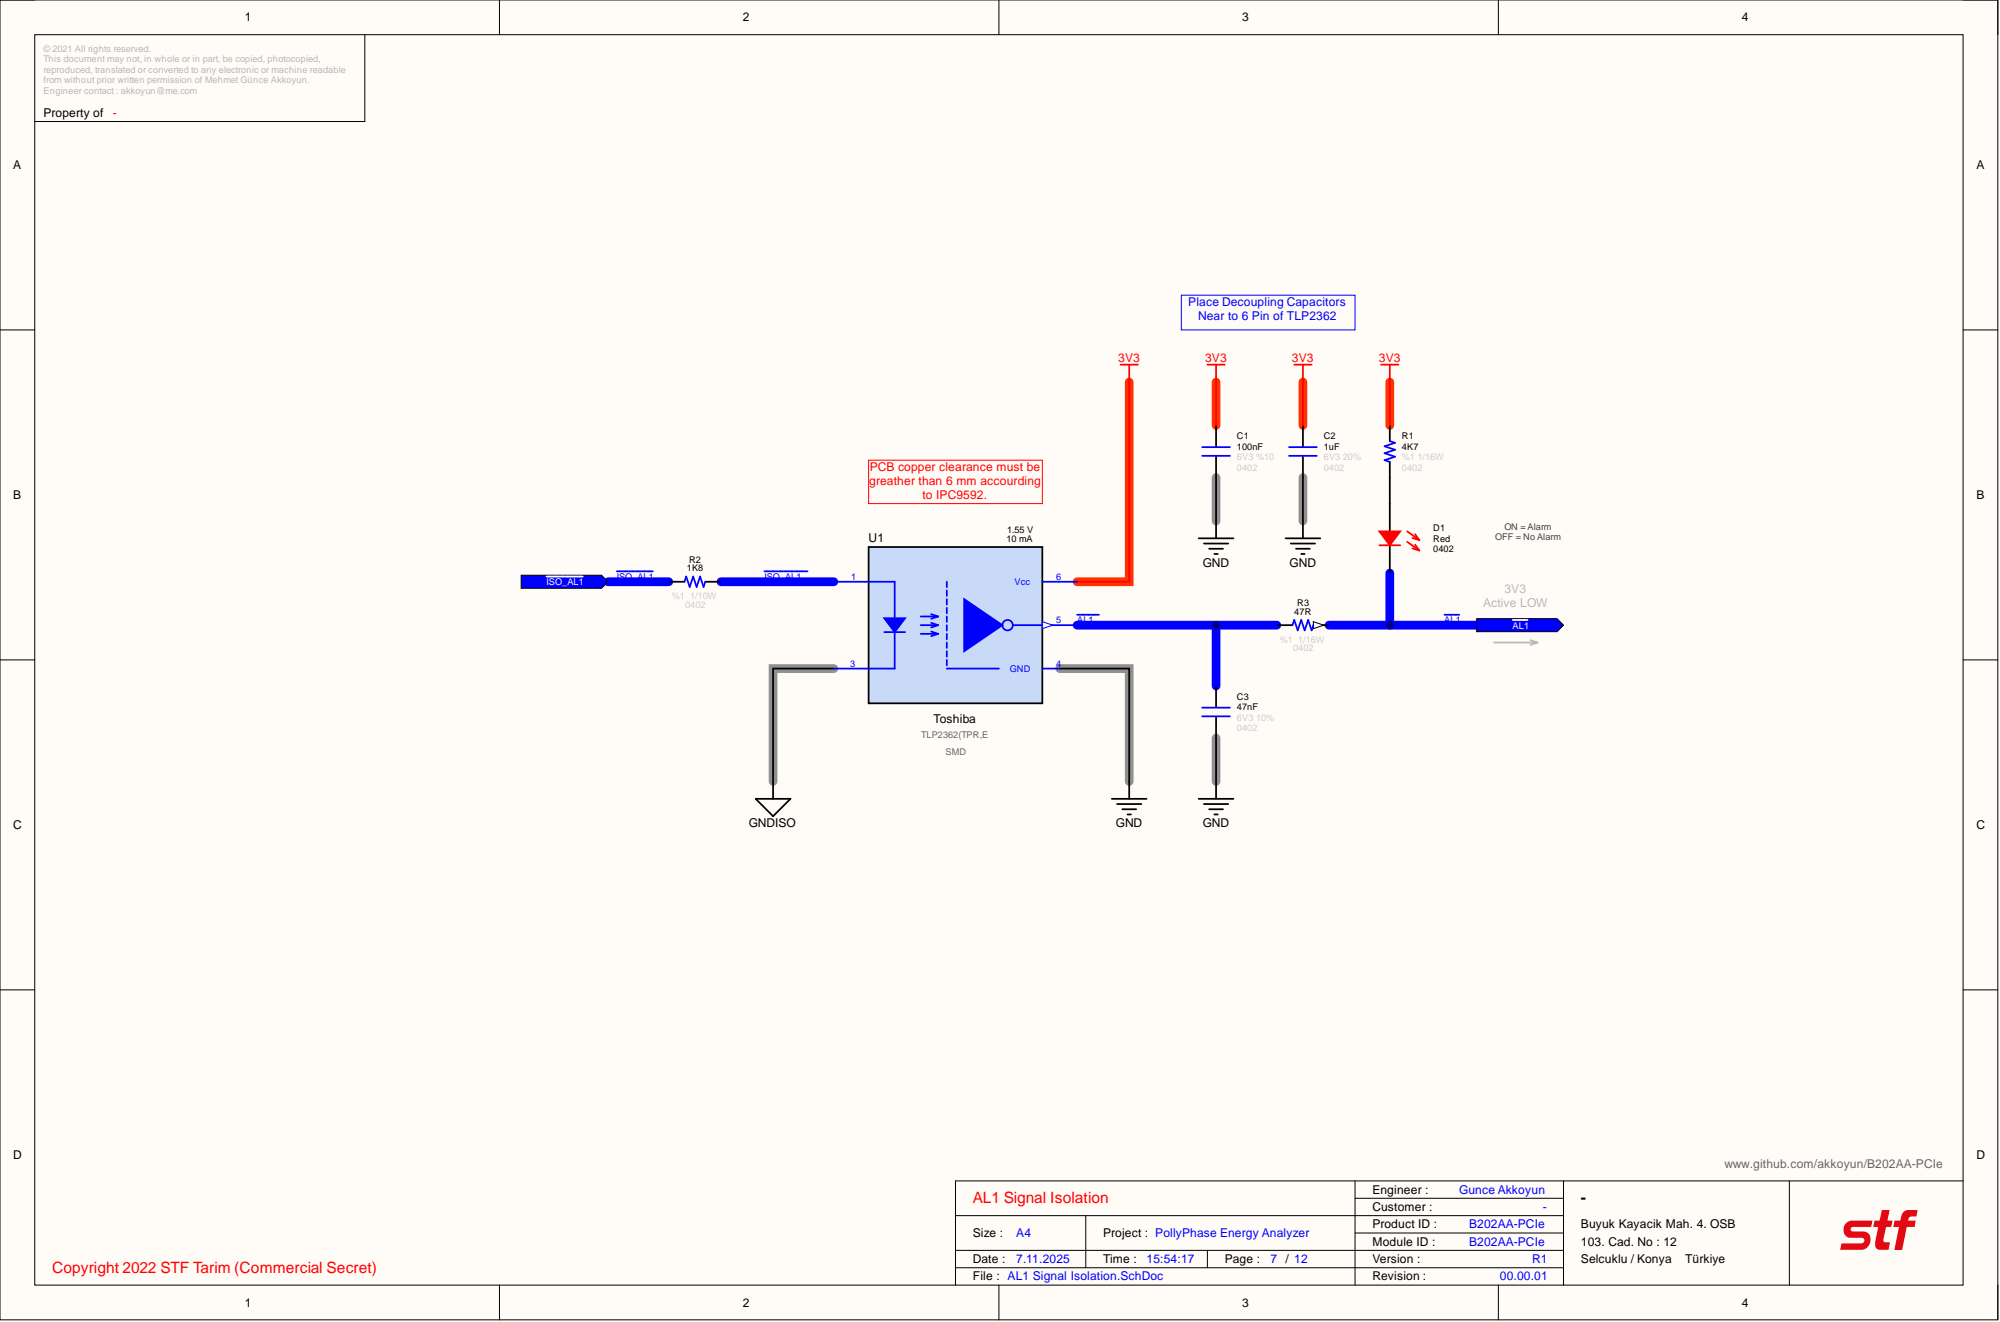
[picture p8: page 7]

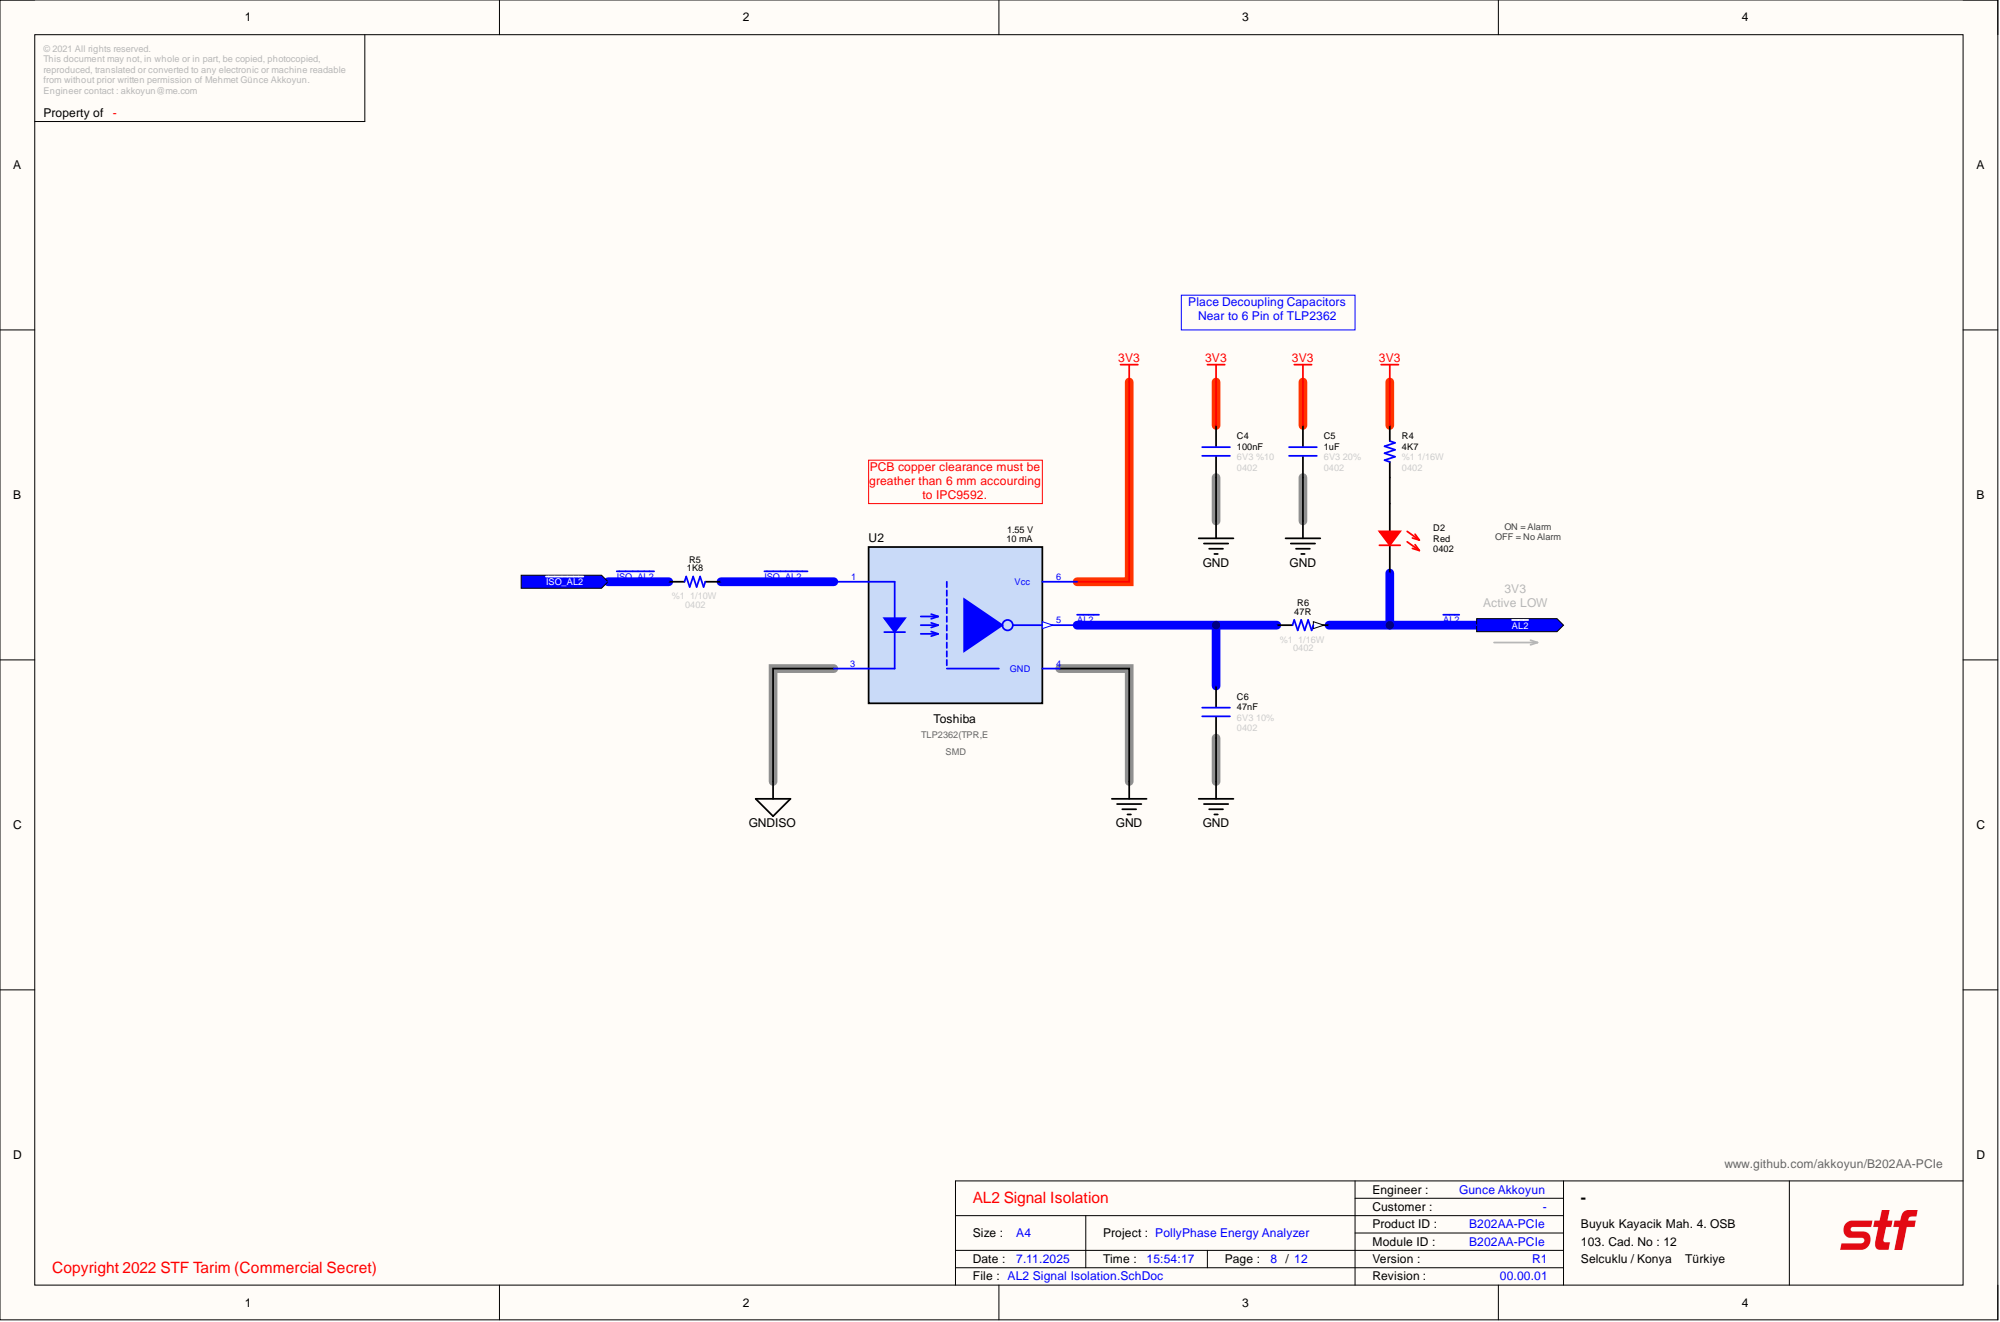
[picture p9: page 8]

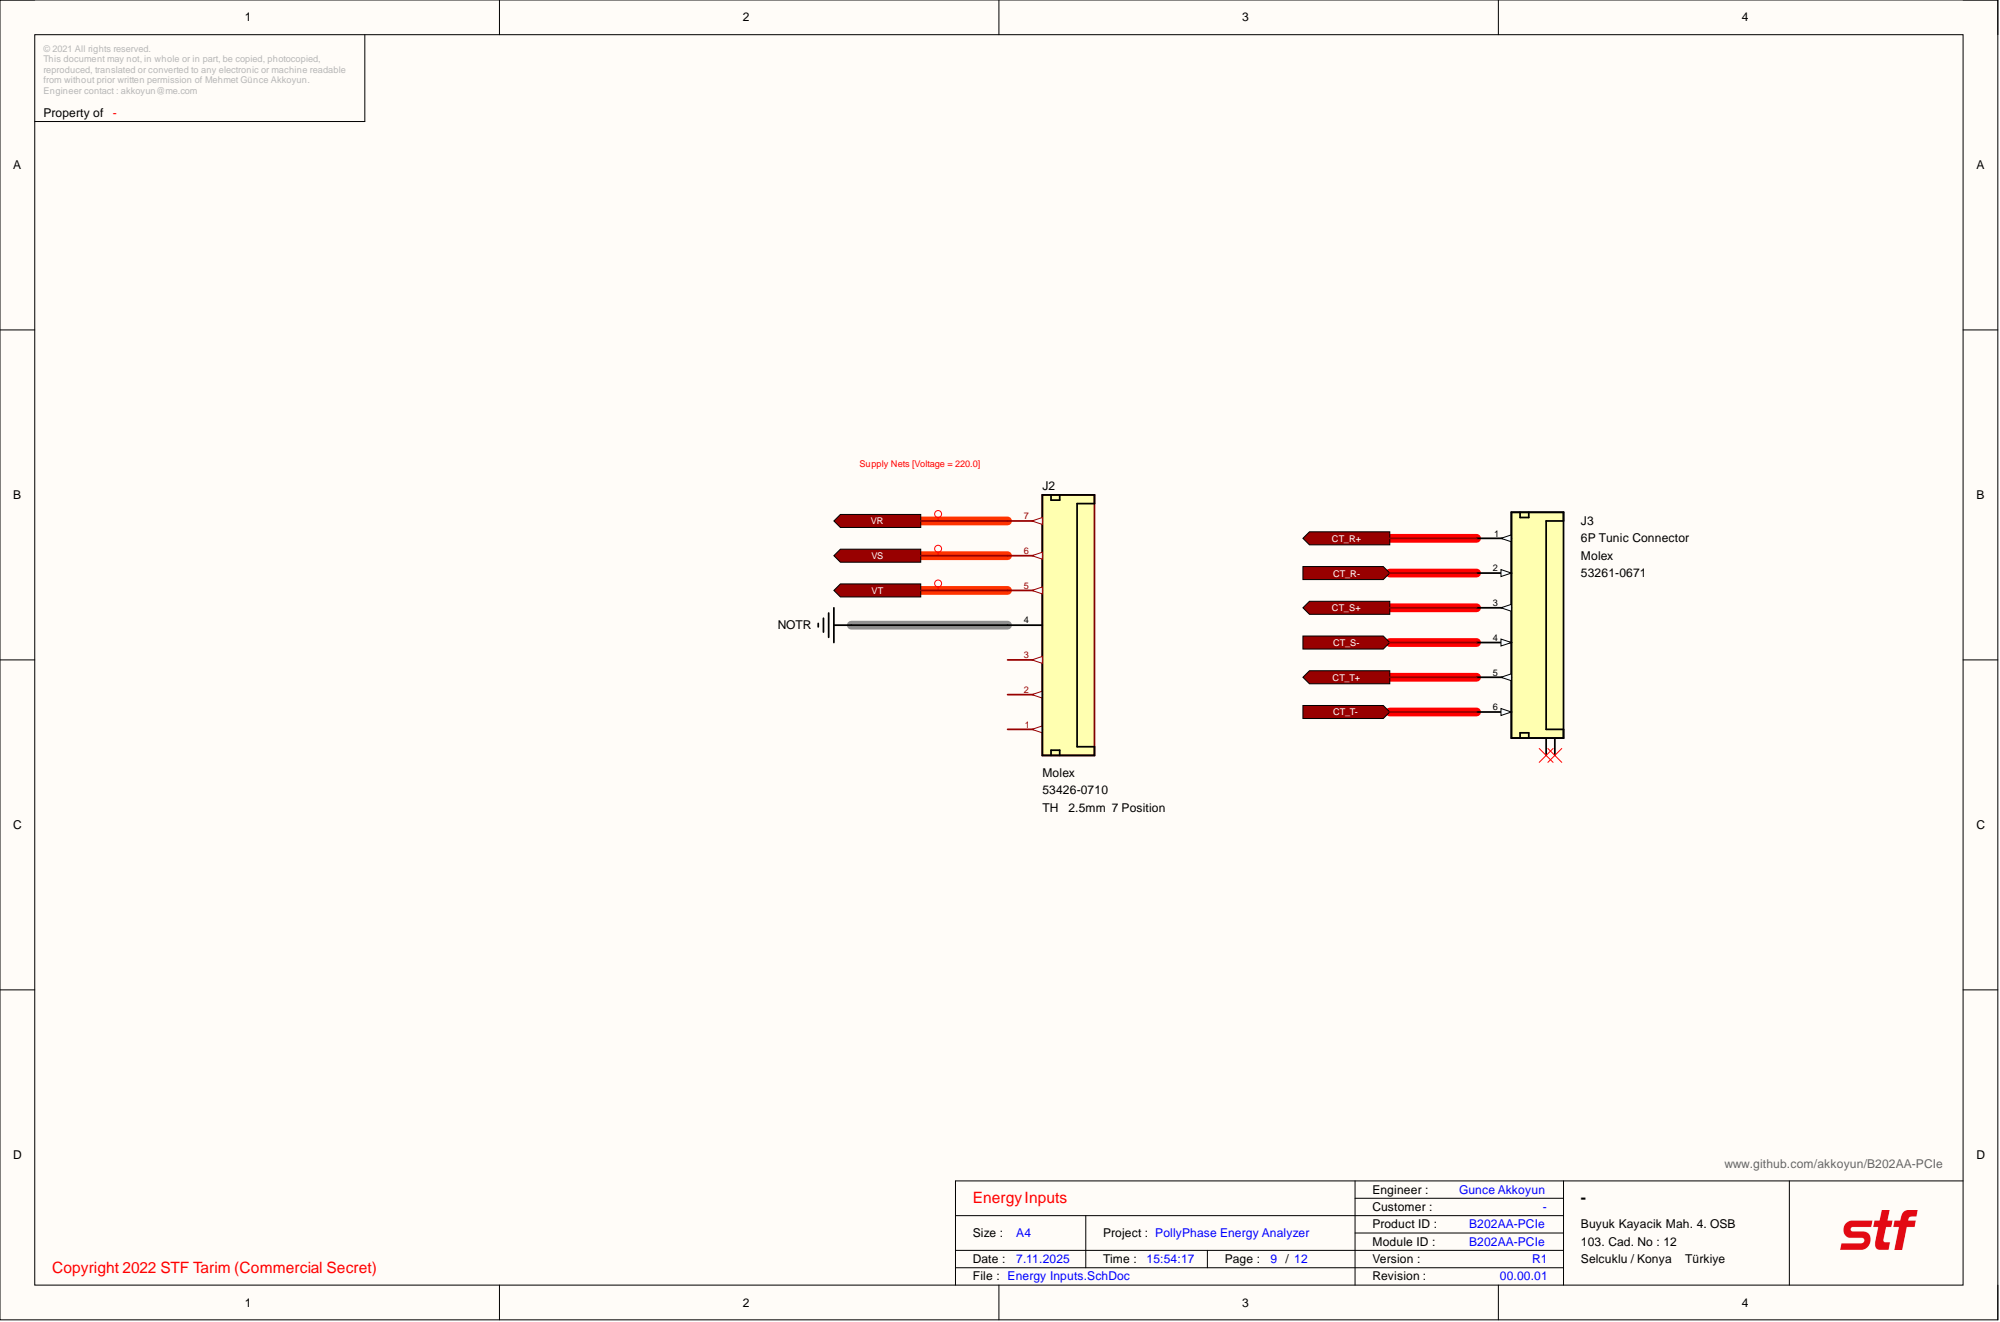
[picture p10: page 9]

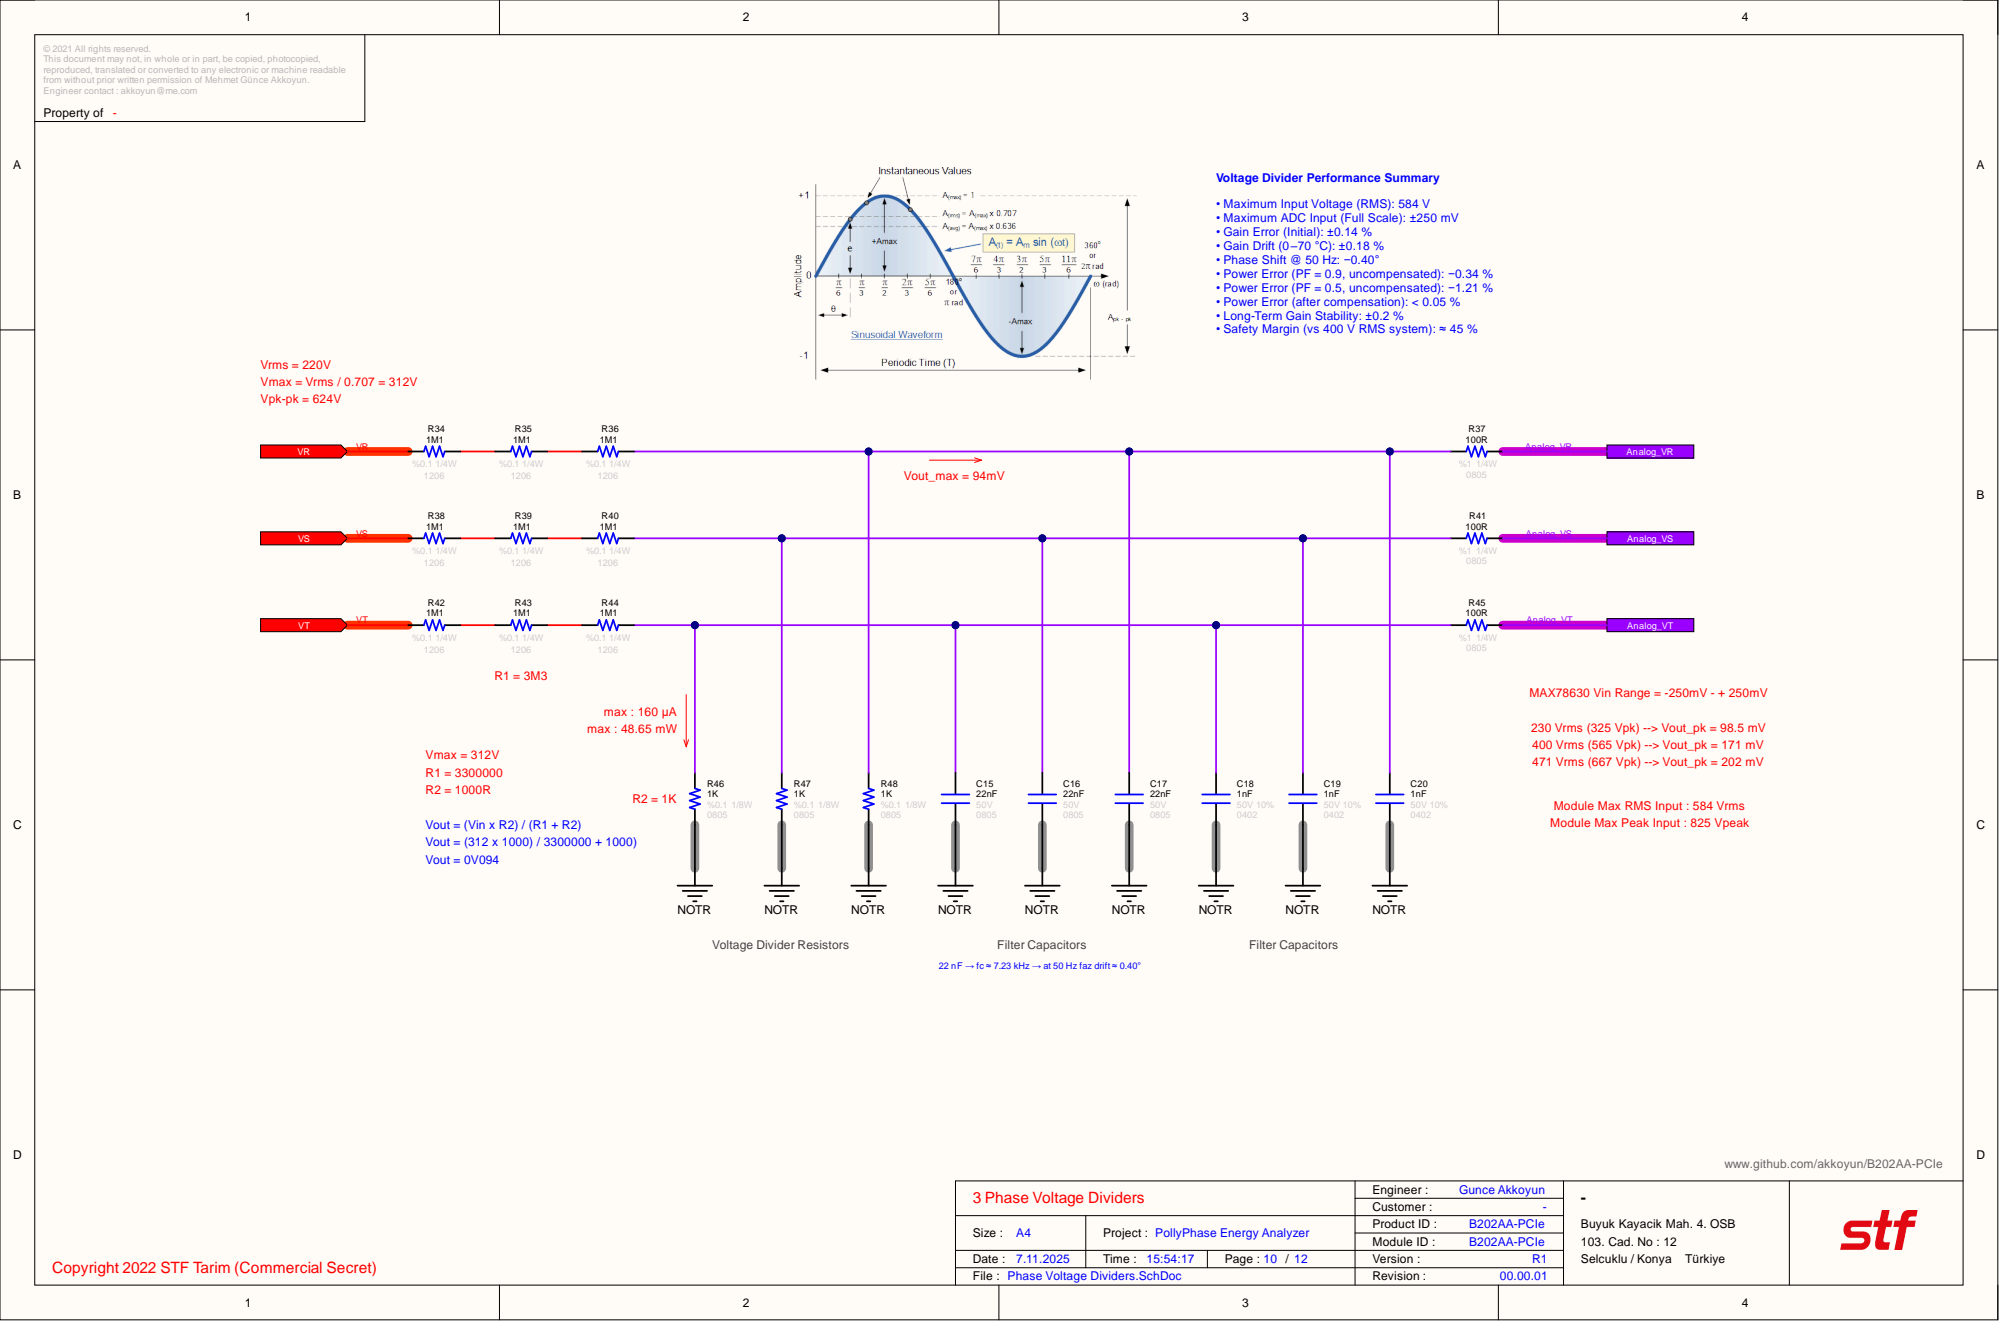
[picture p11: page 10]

Voltage Divider Performance Summary

• Maximum Input Voltage (RMS): 584 V
• Maximum ADC Input (Full Scale): ±250 mV
• Gain Error (Initial): ±0.14 %
• Gain Drift (0–70 °C): ±0.18 %
• Phase Shift @ 50 Hz: −0.40°
• Power Error (PF = 0.9, uncompensated): −0.34 %
• Power Error (PF = 0.5, uncompensated): −1.21 %
• Power Error (after compensation): < 0.05 %
• Long-Term Gain Stability: ±0.2 %
• Safety Margin (vs 400 V RMS system): ≈ 45 %

Module Max RMS Input : 584 Vrms
Module Max Peak Input : 825 Vpeak

22 nF → fc ≈ 7.23 kHz → at 50 Hz faz drift ≈ 0.40°

www.github.com/akkoyun/B202AA-PCIe

File : Phase Voltage Dividers.SchDoc

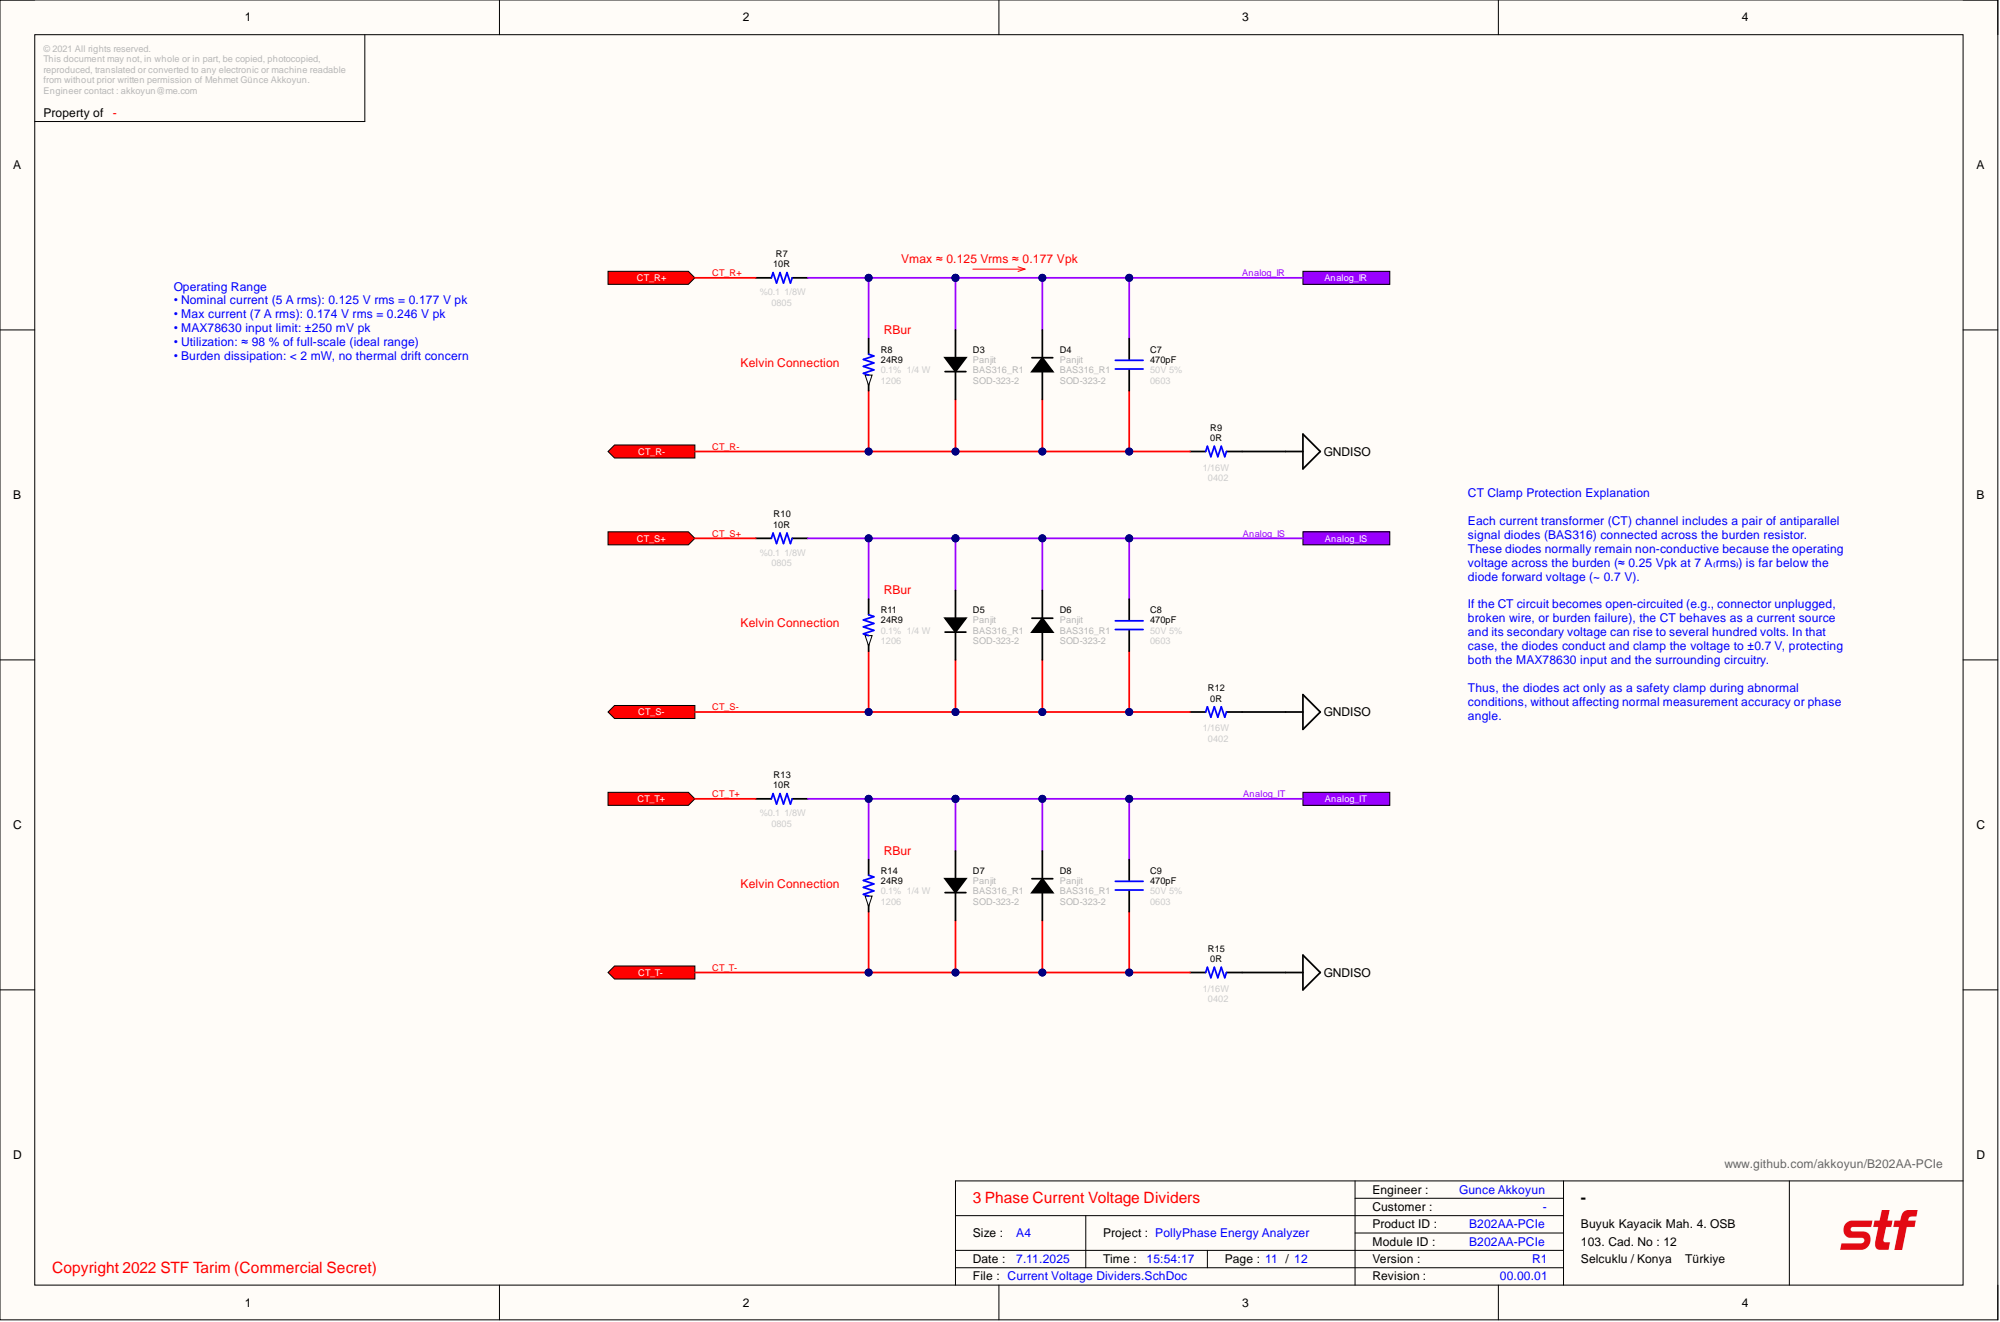
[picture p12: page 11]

Operating Range
• Nominal current (5 A rms): 0.125 V rms = 0.177 V pk
• Max current (7 A rms): 0.174 V rms = 0.246 V pk
• MAX78630 input limit: ±250 mV pk
• Utilization: ≈ 98 % of full-scale (ideal range)

CT Clamp Protection Explanation

Each current transformer (CT) channel includes a pair of antiparallel
signal diodes (BAS316) connected across the burden resistor.
These diodes normally remain non-conductive because the operating
voltage across the burden (≈ 0.25 Vpk at 7 A₍rms₎) is far below the
diode forward voltage (~ 0.7 V).

If the CT circuit becomes open-circuited (e.g., connector unplugged,
broken wire, or burden failure), the CT behaves as a current source
and its secondary voltage can rise to several hundred volts. In that
case, the diodes conduct and clamp the voltage to ±0.7 V, protecting
both the MAX78630 input and the surrounding circuitry.

Thus, the diodes act only as a safety clamp during abnormal
conditions, without affecting normal measurement accuracy or phase
angle.

www.github.com/akkoyun/B202AA-PCIe

3 Phase Current Voltage Dividers

File : Current Voltage Dividers.SchDoc

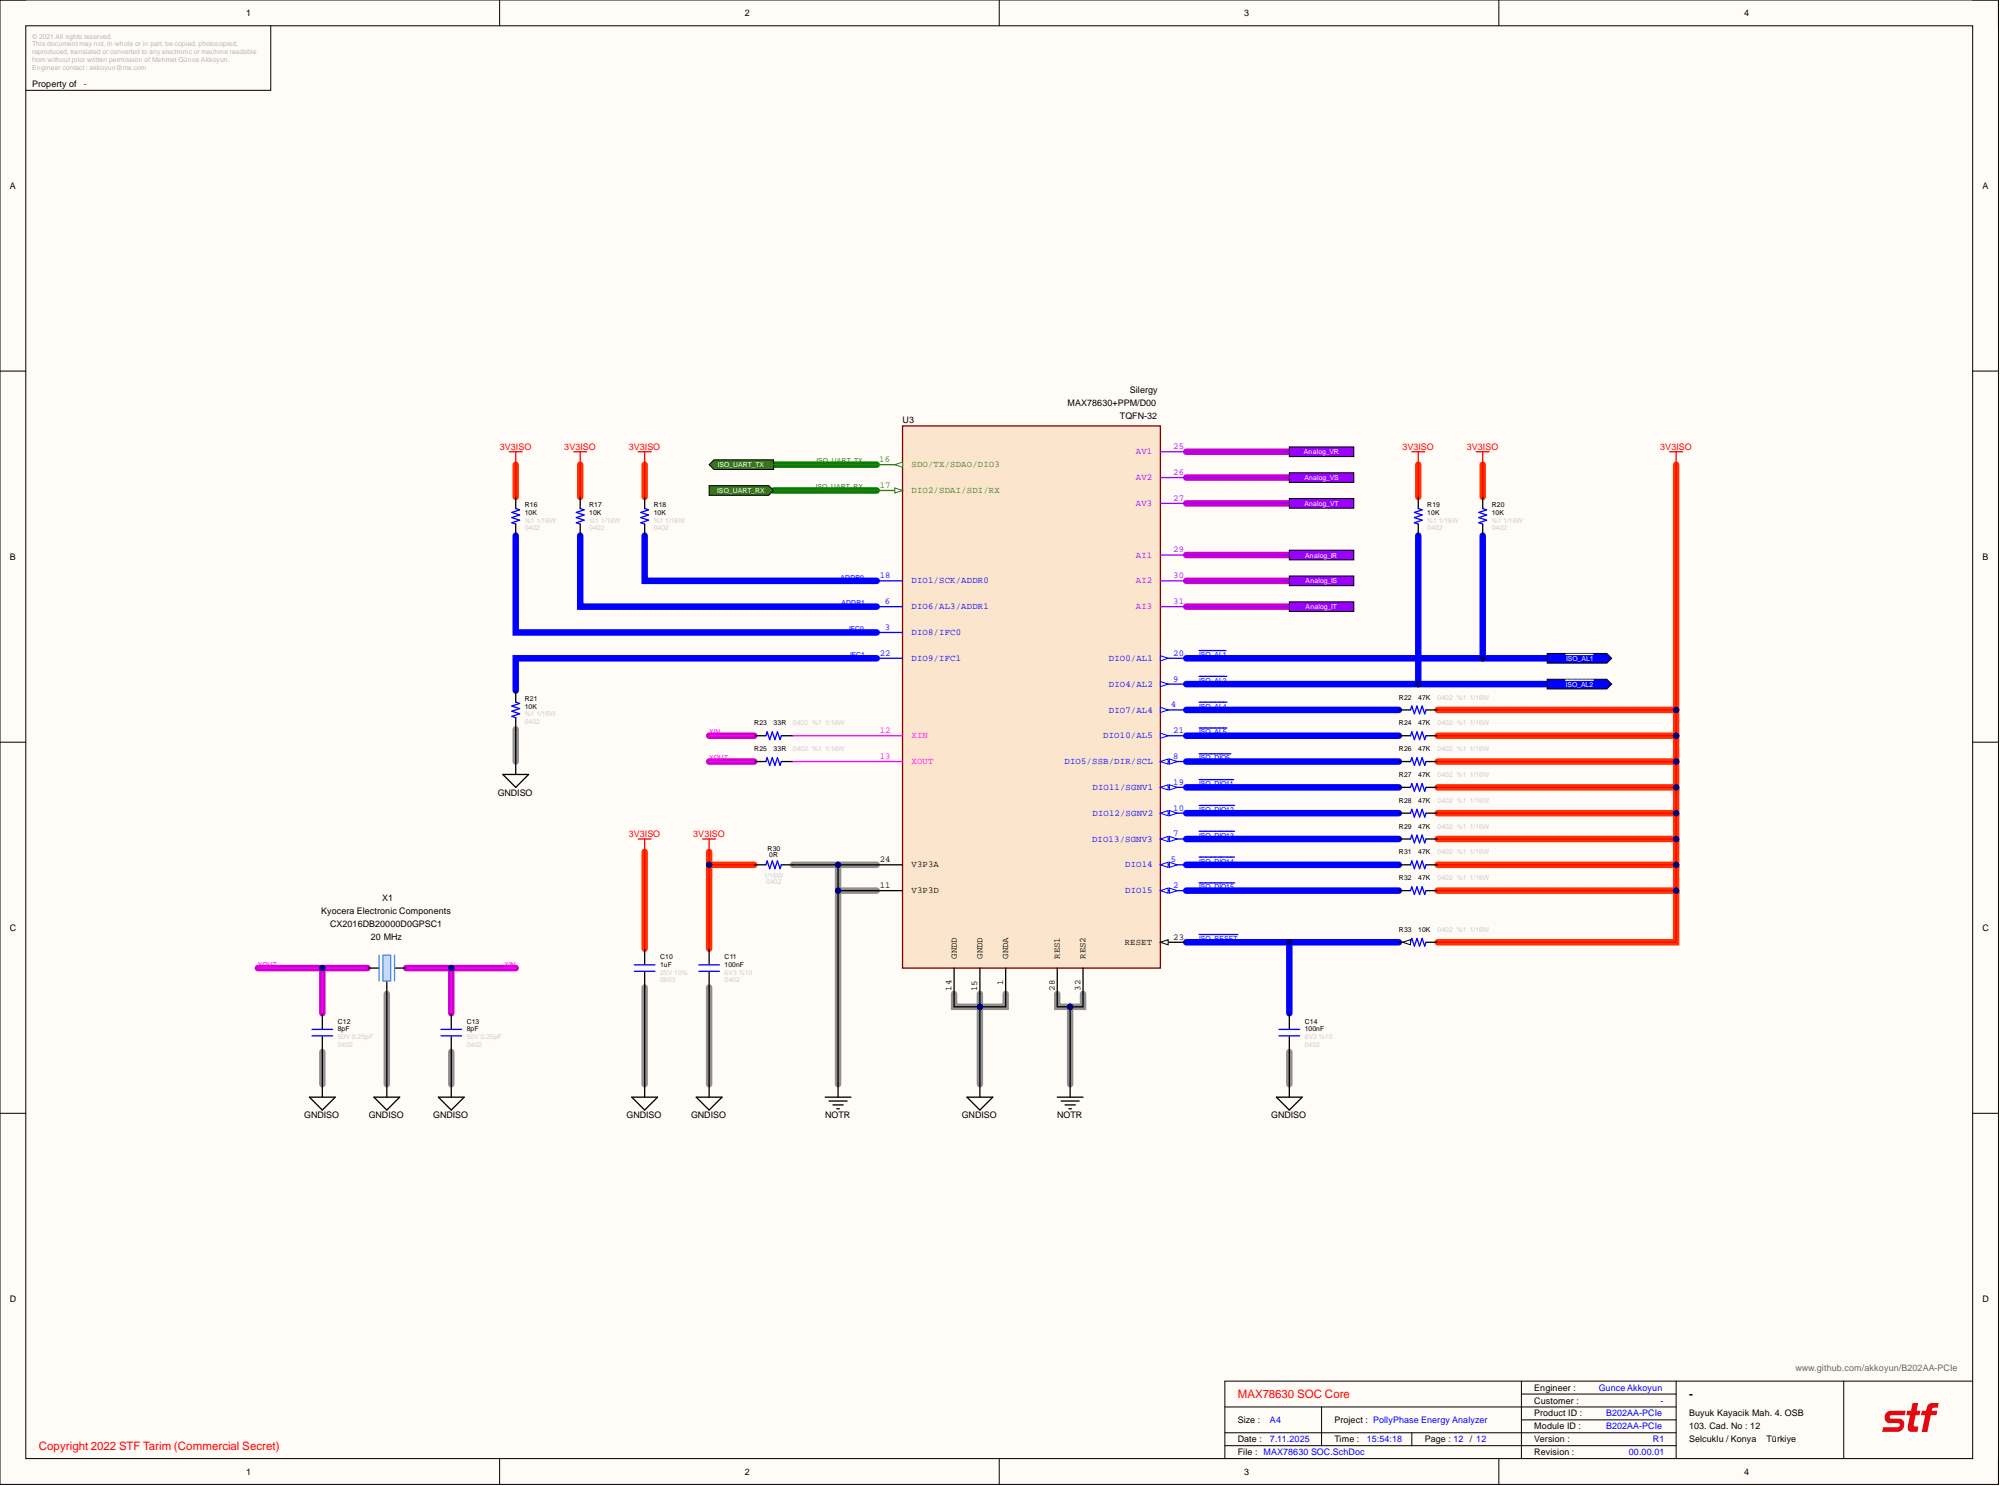
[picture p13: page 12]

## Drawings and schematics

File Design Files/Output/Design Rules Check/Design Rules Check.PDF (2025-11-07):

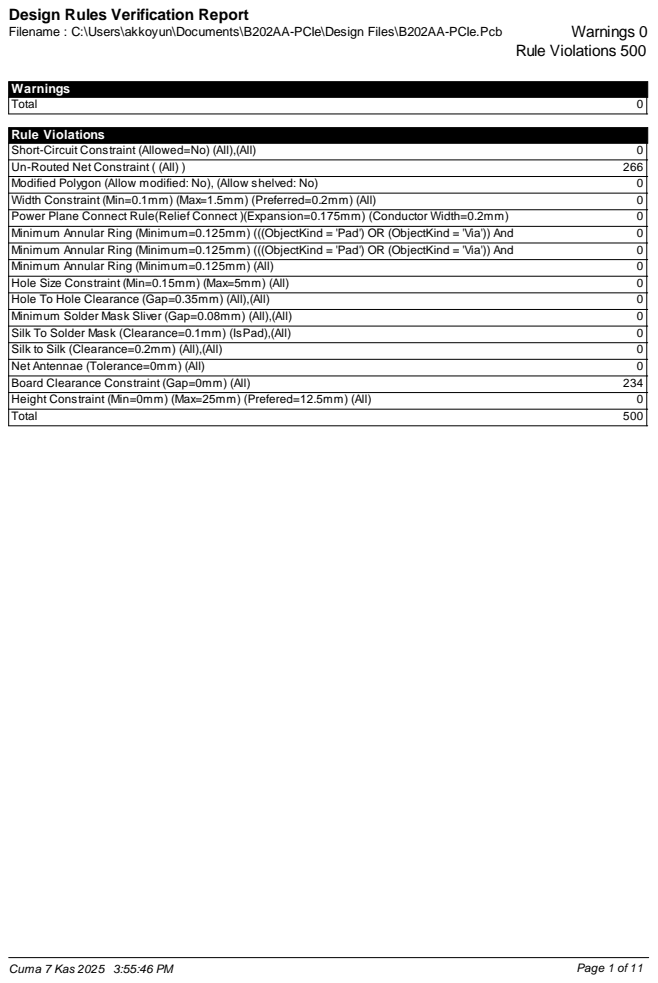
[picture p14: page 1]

Design Rules Verification Report

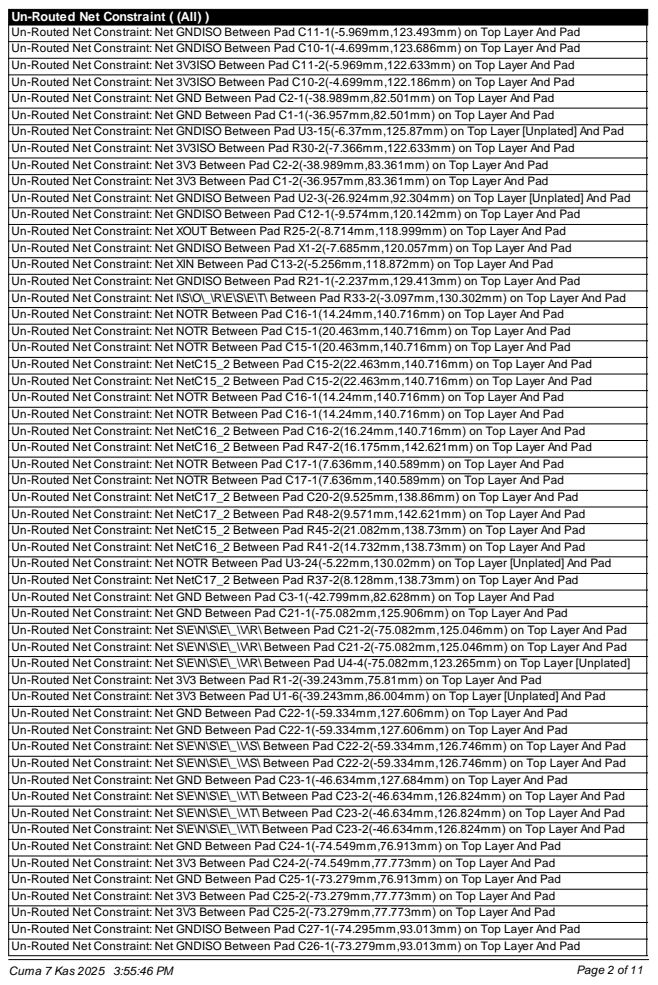
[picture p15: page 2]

Un-Routed Net Constraint ( (All) )
Un-Routed Net Constraint: Net GNDISO Between Pad C11-1(-5.969mm,123.493mm) on Top Layer And Pad
Un-Routed Net Constraint: Net GNDISO Between Pad C10-1(-4.699mm,123.686mm) on Top Layer And Pad
Un-Routed Net Constraint: Net 3V3ISO Between Pad C11-2(-5.969mm,122.633mm) on Top Layer And Pad
Un-Routed Net Constraint: Net 3V3ISO Between Pad C10-2(-4.699mm,122.186mm) on Top Layer And Pad
Un-Routed Net Constraint: Net GND Between Pad C2-1(-38.989mm,82.501mm) on Top Layer And Pad
Un-Routed Net Constraint: Net GND Between Pad C1-1(-36.957mm,82.501mm) on Top Layer And Pad
Un-Routed Net Constraint: Net GNDISO Between Pad U3-15(-6.37mm,125.87mm) on Top Layer [Unplated] And Pad
Un-Routed Net Constraint: Net 3V3ISO Between Pad R30-2(-7.366mm,122.633mm) on Top Layer And Pad
Un-Routed Net Constraint: Net 3V3 Between Pad C2-2(-38.989mm,83.361mm) on Top Layer And Pad
Un-Routed Net Constraint: Net 3V3 Between Pad C1-2(-36.957mm,83.361mm) on Top Layer And Pad
Un-Routed Net Constraint: Net GNDISO Between Pad U2-3(-26.924mm,92.304mm) on Top Layer [Unplated] And Pad
Un-Routed Net Constraint: Net GNDISO Between Pad C12-1(-9.574mm,120.142mm) on Top Layer And Pad
Un-Routed Net Constraint: Net XOUT Between Pad R25-2(-8.714mm,118.999mm) on Top Layer And Pad
Un-Routed Net Constraint: Net GNDISO Between Pad X1-2(-7.685mm,120.057mm) on Top Layer And Pad
Un-Routed Net Constraint: Net XIN Between Pad C13-2(-5.256mm,118.872mm) on Top Layer And Pad
Un-Routed Net Constraint: Net GNDISO Between Pad R21-1(-2.237mm,129.413mm) on Top Layer And Pad
Un-Routed Net Constraint: Net I\S\O\_\R\E\S\E\T\ Between Pad R33-2(-3.097mm,130.302mm) on Top Layer And Pad
Un-Routed Net Constraint: Net NOTR Between Pad C16-1(14.24mm,140.716mm) on Top Layer And Pad
Un-Routed Net Constraint: Net NOTR Between Pad C15-1(20.463mm,140.716mm) on Top Layer And Pad
Un-Routed Net Constraint: Net NetC15_2 Between Pad C15-2(22.463mm,140.716mm) on Top Layer And Pad
Un-Routed Net Constraint: Net NetC16_2 Between Pad C16-2(16.24mm,140.716mm) on Top Layer And Pad
Un-Routed Net Constraint: Net NetC16_2 Between Pad R47-2(16.175mm,142.621mm) on Top Layer And Pad
Un-Routed Net Constraint: Net NOTR Between Pad C17-1(7.636mm,140.589mm) on Top Layer And Pad
Un-Routed Net Constraint: Net NetC17_2 Between Pad C20-2(9.525mm,138.86mm) on Top Layer And Pad
Un-Routed Net Constraint: Net NetC17_2 Between Pad R48-2(9.571mm,142.621mm) on Top Layer And Pad
Un-Routed Net Constraint: Net NetC15_2 Between Pad R45-2(21.082mm,138.73mm) on Top Layer And Pad
Un-Routed Net Constraint: Net NetC16_2 Between Pad R41-2(14.732mm,138.73mm) on Top Layer And Pad
Un-Routed Net Constraint: Net NOTR Between Pad U3-24(-5.22mm,130.02mm) on Top Layer [Unplated] And Pad
Un-Routed Net Constraint: Net NetC17_2 Between Pad R37-2(8.128mm,138.73mm) on Top Layer And Pad
Un-Routed Net Constraint: Net GND Between Pad C3-1(-42.799mm,82.628mm) on Top Layer And Pad
Un-Routed Net Constraint: Net GND Between Pad C21-1(-75.082mm,125.906mm) on Top Layer And Pad
Un-Routed Net Constraint: Net S\E\N\S\E\_\V\R\ Between Pad C21-2(-75.082mm,125.046mm) on Top Layer And Pad
Un-Routed Net Constraint: Net S\E\N\S\E\_\V\R\ Between Pad U4-4(-75.082mm,123.265mm) on Top Layer [Unplated]
Un-Routed Net Constraint: Net 3V3 Between Pad R1-2(-39.243mm,75.81mm) on Top Layer And Pad
Un-Routed Net Constraint: Net 3V3 Between Pad U1-6(-39.243mm,86.004mm) on Top Layer [Unplated] And Pad
Un-Routed Net Constraint: Net GND Between Pad C22-1(-59.334mm,127.606mm) on Top Layer And Pad
Un-Routed Net Constraint: Net S\E\N\S\E\_\V\S\ Between Pad C22-2(-59.334mm,126.746mm) on Top Layer And Pad
Un-Routed Net Constraint: Net GND Between Pad C23-1(-46.634mm,127.684mm) on Top Layer And Pad
Un-Routed Net Constraint: Net S\E\N\S\E\_\V\T\ Between Pad C23-2(-46.634mm,126.824mm) on Top Layer And Pad
Un-Routed Net Constraint: Net GND Between Pad C24-1(-74.549mm,76.913mm) on Top Layer And Pad
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

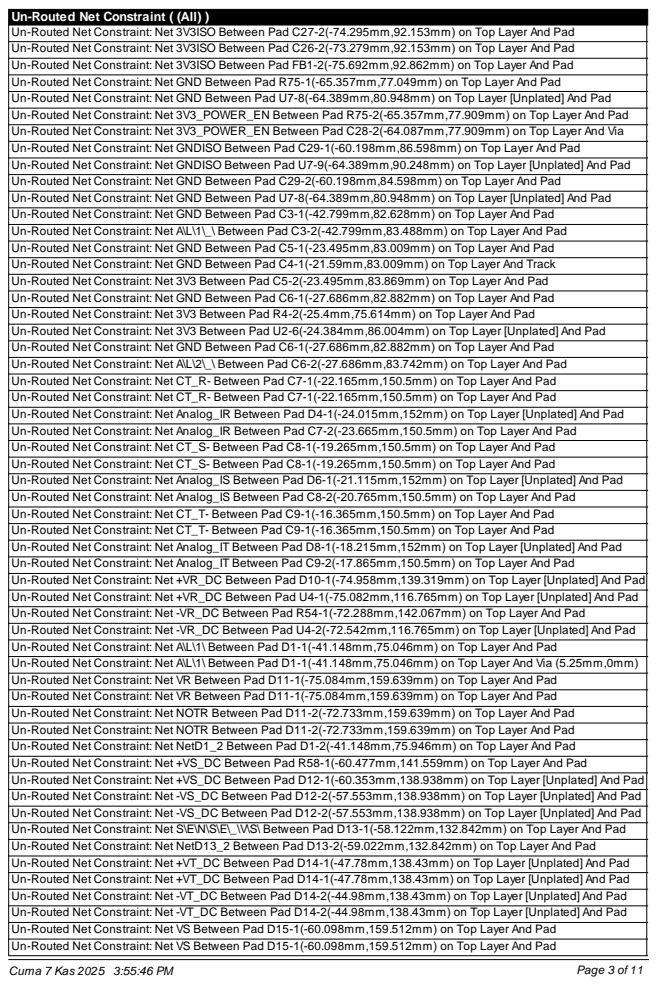
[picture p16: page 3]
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

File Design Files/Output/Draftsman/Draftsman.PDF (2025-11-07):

A

B

C

D

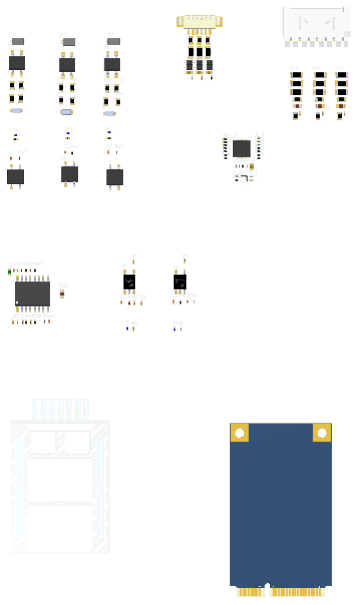
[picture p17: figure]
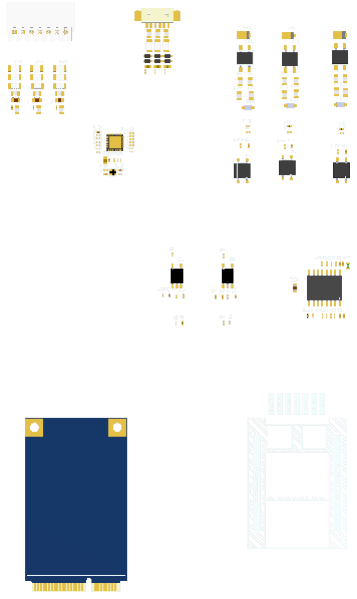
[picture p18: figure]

1 | 1
2 | 2
3 | 3
4 | 4

B202AA-PCIe module is an energy measurement module (EMM) for poly phase power monitoring systems. It is designed for real-time monitoring for a variety of typical three-phase configurations in industrial applications. It is available in a mini PCIe size PCB module.

The B202AA-PCIe provides up to six analog inputs for interfacing to voltage and current sensors. Scaled voltages from the sensors are fed to the single converter front-end utilizing a high-resolution delta-sigma converter. Supported current sensors include current transformers (CT), Rogowski coils, and resistive shunts.

An embedded 24-bit measurement processor and firmware perform all necessary computations and data formatting for accurate reporting to the host. With integrated flash memory for storing nonvolatile calibration coefficients and device configuration settings, the B202 is capable of being a completely autonomous solution.

Engineer :

Buyuk Kayacik Mah. 4. OSB
103. Cad. No : 12
Selcuklu / KonyaTürkiye

Gunce Akkoyun
Customer :
Product ID :
Module ID :

Revision :

Version :

B202AA-PCIe

R1
00.00.01

www.github.com/akkoyun/B202AA-PCIe

File : B202AA-PCIe.PCBDwf

Date : 7.11.2025 | Time : 15:54 | Page : 1 / 6
Size : A4 | Project :PollyPhase Energy Analyzer

B202AA-PCIe

© 2021 All rights reserved.
This document may not, in whole or in part, be copied, photocopied, reproduced, translated or converted to any electronic or machine readable from without prior written permission of Mehmet Günce Akkoyun.
Property of-

Copyright 2022 STF Tarim (Commercial Secret)

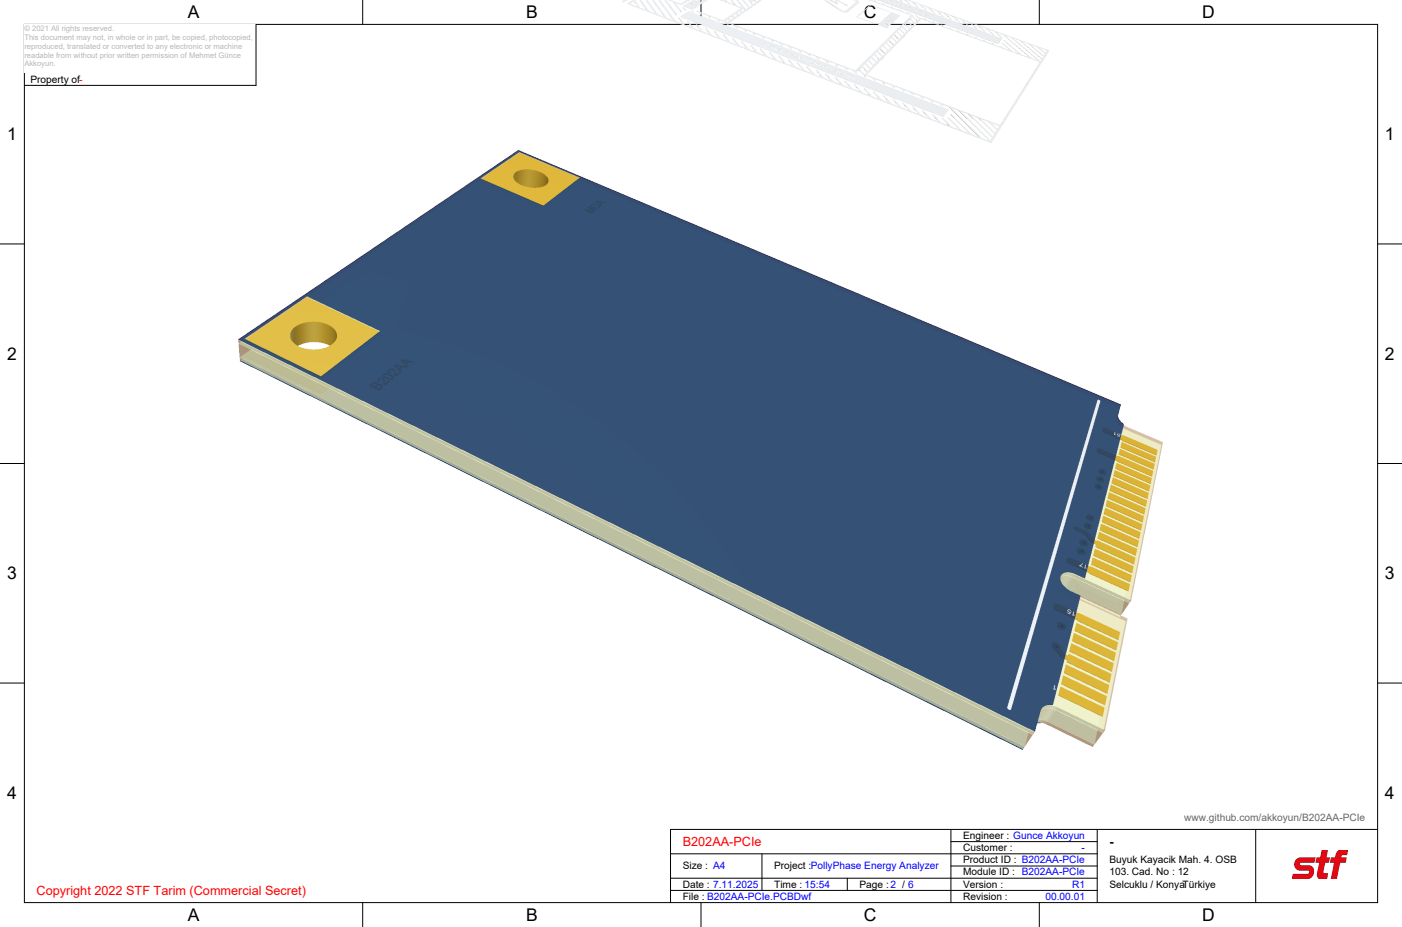
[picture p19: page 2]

www.github.com/akkoyun/B202AA-PCIe

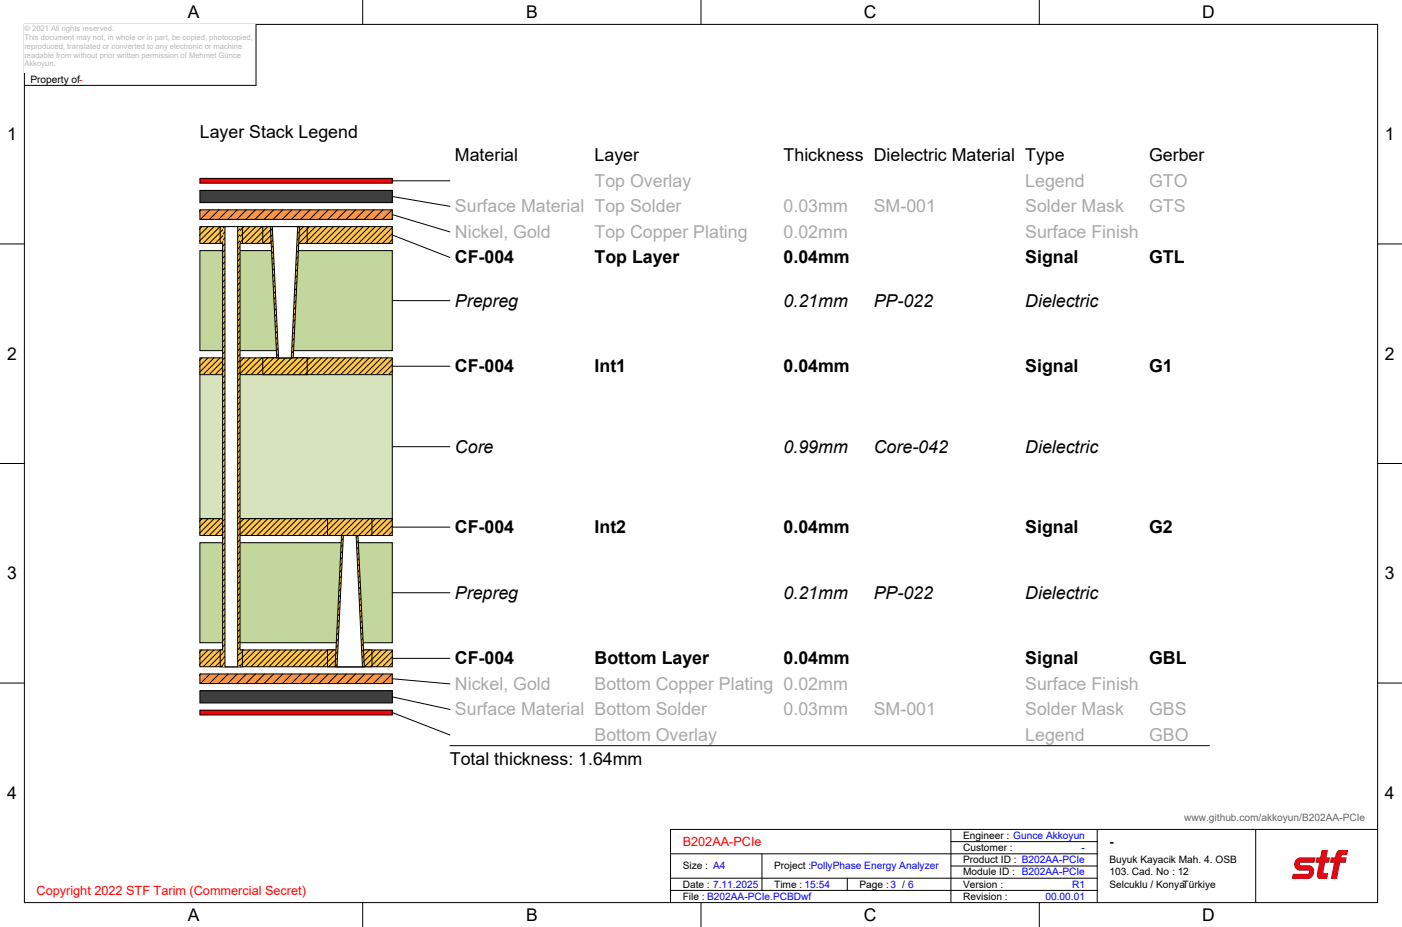
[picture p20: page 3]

www.github.com/akkoyun/B202AA-PCIe

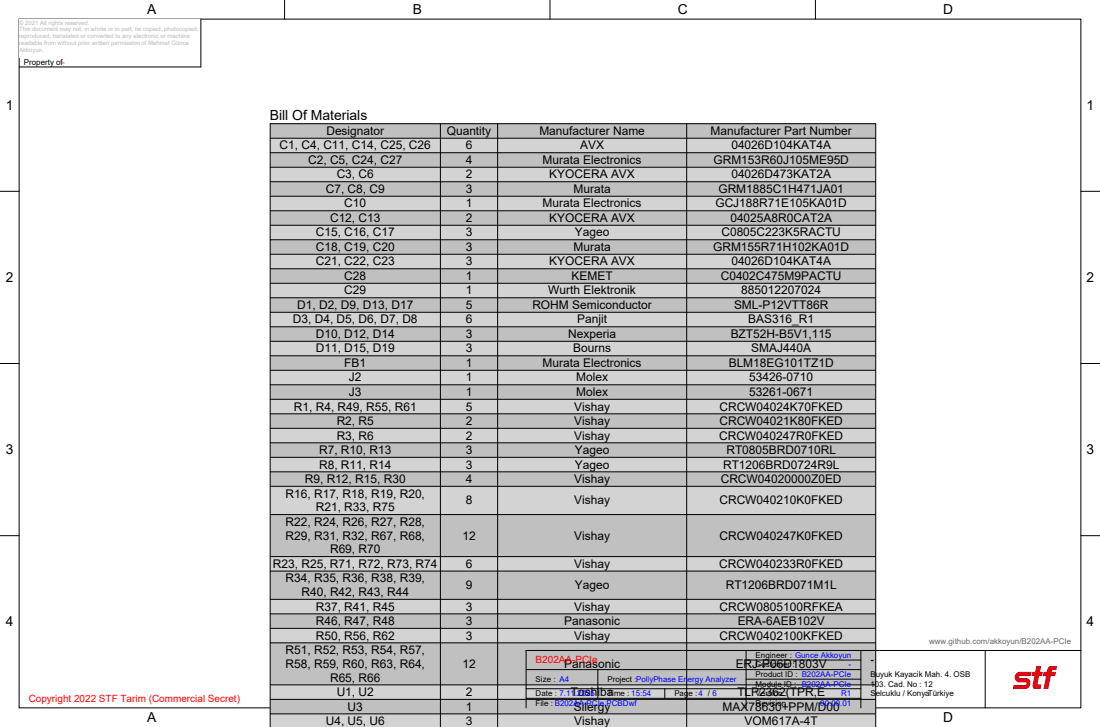
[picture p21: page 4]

Designator | Quantity | Manufacturer Name | Manufacturer Part Number

C1, C4, C11, C14, C25, C26 | 6 | AVX | 04026D104KAT4A
C2, C5, C24, C27 | 4 | Murata Electronics | GRM153R60J105ME95D
C3, C6 | 2 | KYOCERA AVX | 04026D473KAT2A
C7, C8, C9 | 3 | Murata | GRM1885C1H471JA01
C10 | 1 | Murata Electronics | GCJ188R71E105KA01D
C12, C13 | 2 | KYOCERA AVX | 04025A8R0CAT2A
C15, C16, C17 | 3 | Yageo | C0805C223K5RACTU
C18, C19, C20 | 3 | Murata | GRM155R71H102KA01D
C21, C22, C23 | 3 | KYOCERA AVX | 04026D104KAT4A
C28 | 1 | KEMET | C0402C475M9PACTU
C29 | 1 | Wurth Elektronik | 885012207024

D1, D2, D9, D13, D17 | 5 | ROHM Semiconductor | SML-P12VTT86R
D3, D4, D5, D6, D7, D8 | 6 | Panjit | BAS316_R1
D10, D12, D14 | 3 | Nexperia | BZT52H-B5V1,115
D11, D15, D19 | 3 | Bourns | SMAJ440A
FB1 | 1 | Murata Electronics | BLM18EG101TZ1D
J2 | 1 | Molex | 53426-0710
J3 | 1 | Molex | 53261-0671

R1, R4, R49, R55, R61 | 5 | Vishay | CRCW04024K70FKED

R2, R5 | 2 | Vishay | CRCW04021K80FKED
R3, R6 | 2 | Vishay | CRCW040247R0FKED
R7, R10, R13 | 3 | Yageo | RT0805BRD0710RL
R8, R11, R14 | 3 | Yageo | RT1206BRD0724R9L
R9, R12, R15, R30 | 4 | Vishay | CRCW04020000Z0ED
R16, R17, R18, R19, R20, R21, R33, R75 | 8 | Vishay | CRCW040210K0FKED

R22, R24, R26, R27, R28, R29, R31, R32, R67, R68, R69, R70 | 12 | Vishay | CRCW040247K0FKED

R23, R25, R71, R72, R73, R74 | 6 | Vishay | CRCW040233R0FKED
R34, R35, R36, R38, R39, R40, R42, R43, R44 | 9 | Yageo | RT1206BRD071M1L

R37, R41, R45 | 3 | Vishay | CRCW0805100RFKEA
R46, R47, R48 | 3 | Panasonic | ERA-6AEB102V
R50, R56, R62 | 3 | Vishay | CRCW0402100KFKED
R51, R52, R53, R54, R57, R58, R59, R60, R63, R64, R65, R66 | 12

www.github.com/akkoyun/B202AA-PCIe

U1, U2 | 2
U3 | 1
U4, U5, U6 | 3 | | Vishay | VOM617A-4T

Toshiba | | | TLP2362(TPR,E

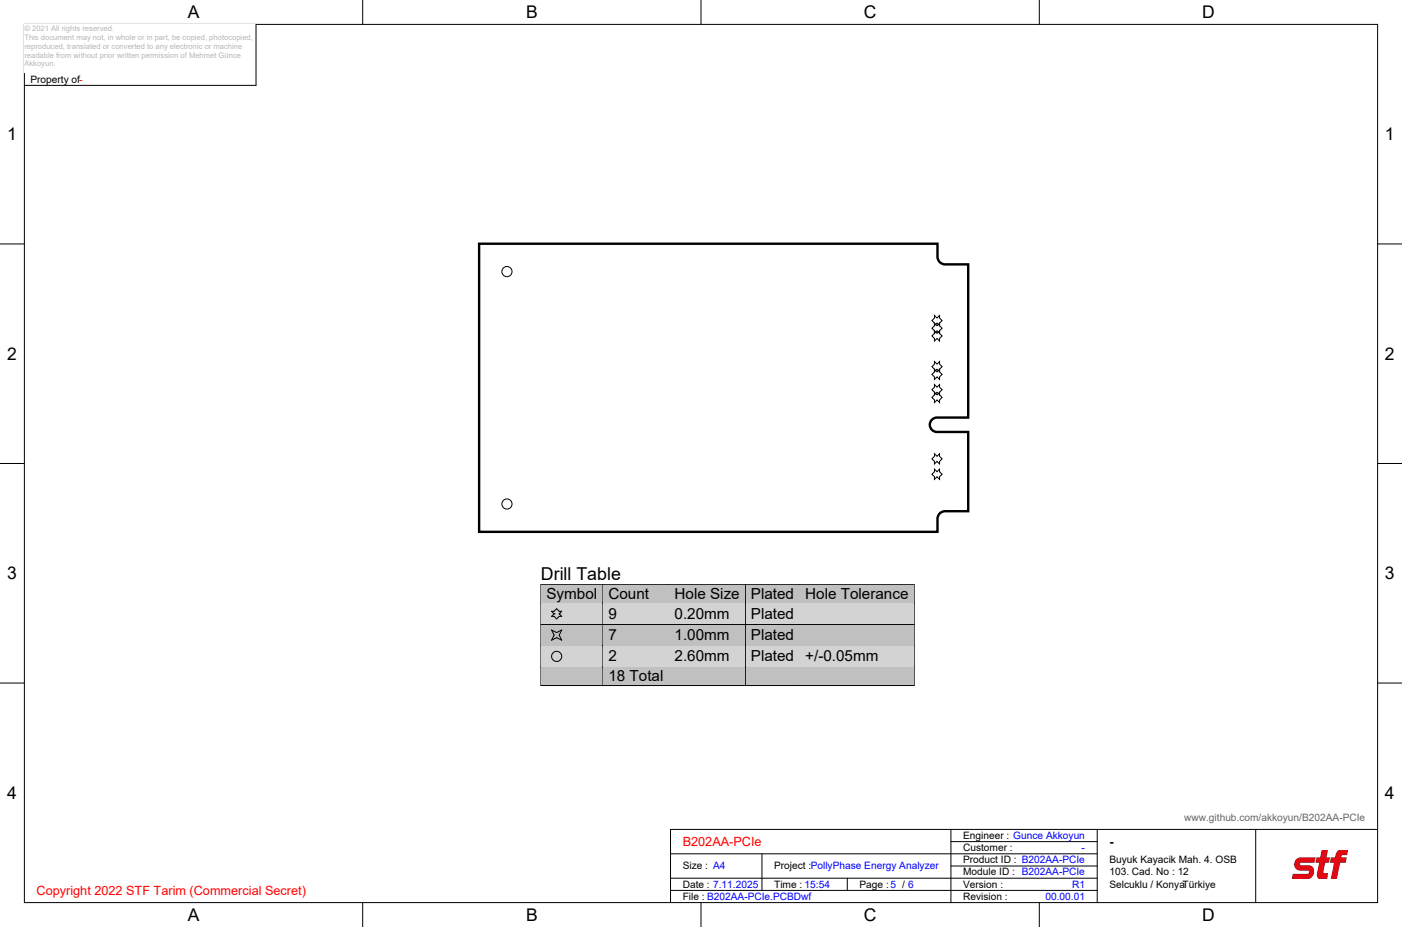
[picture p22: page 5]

Symbol | Count | Hole Size | Plated | Hole Tolerance

9 | 0.20mm | Plated
7 | 1.00mm | Plated
2 | 2.60mm | Plated | +/-0.05mm
18 Total

www.github.com/akkoyun/B202AA-PCIe

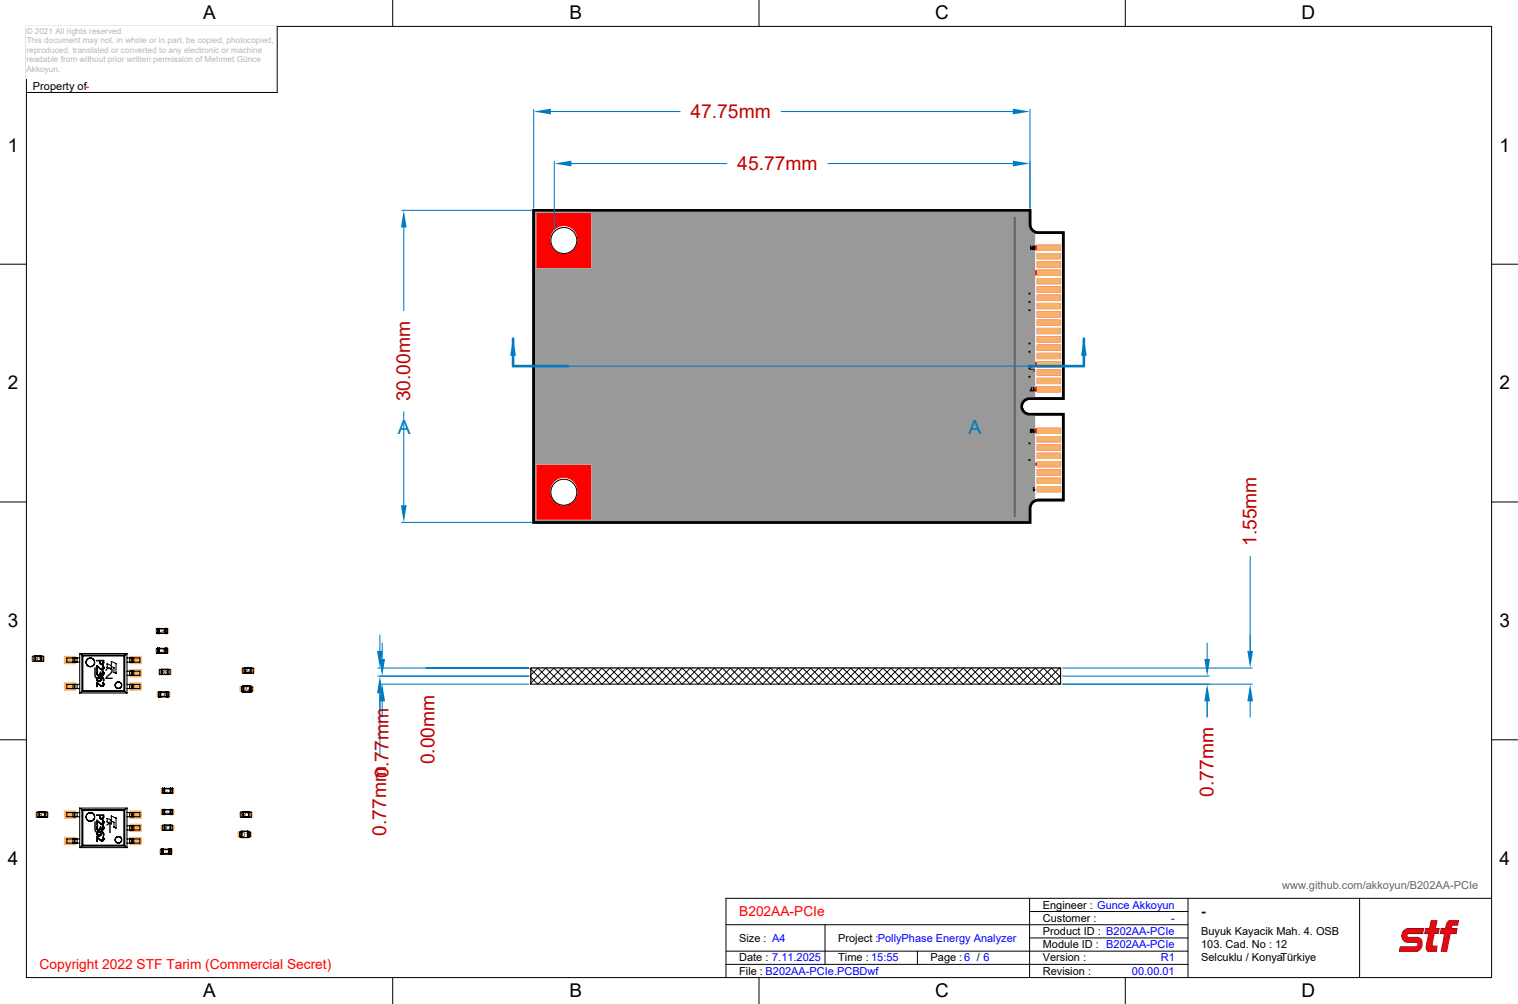
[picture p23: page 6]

www.github.com/akkoyun/B202AA-PCIe

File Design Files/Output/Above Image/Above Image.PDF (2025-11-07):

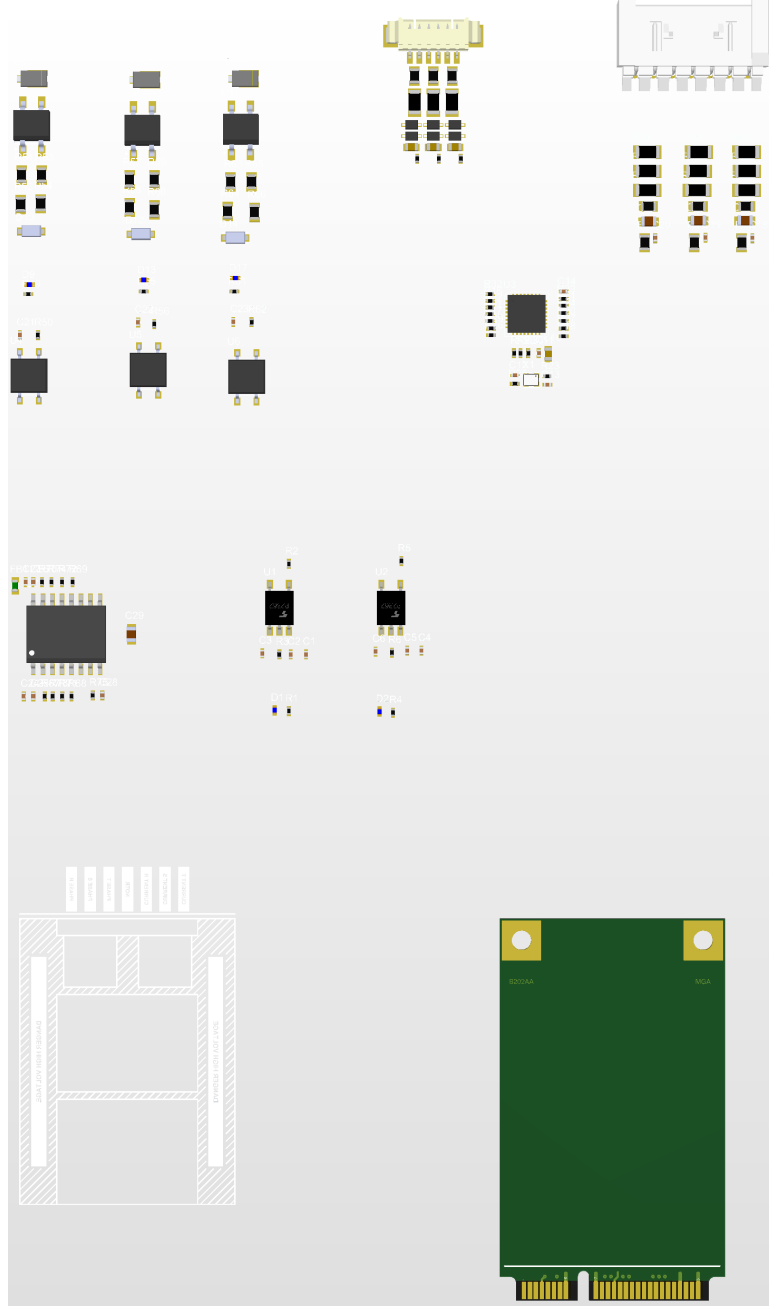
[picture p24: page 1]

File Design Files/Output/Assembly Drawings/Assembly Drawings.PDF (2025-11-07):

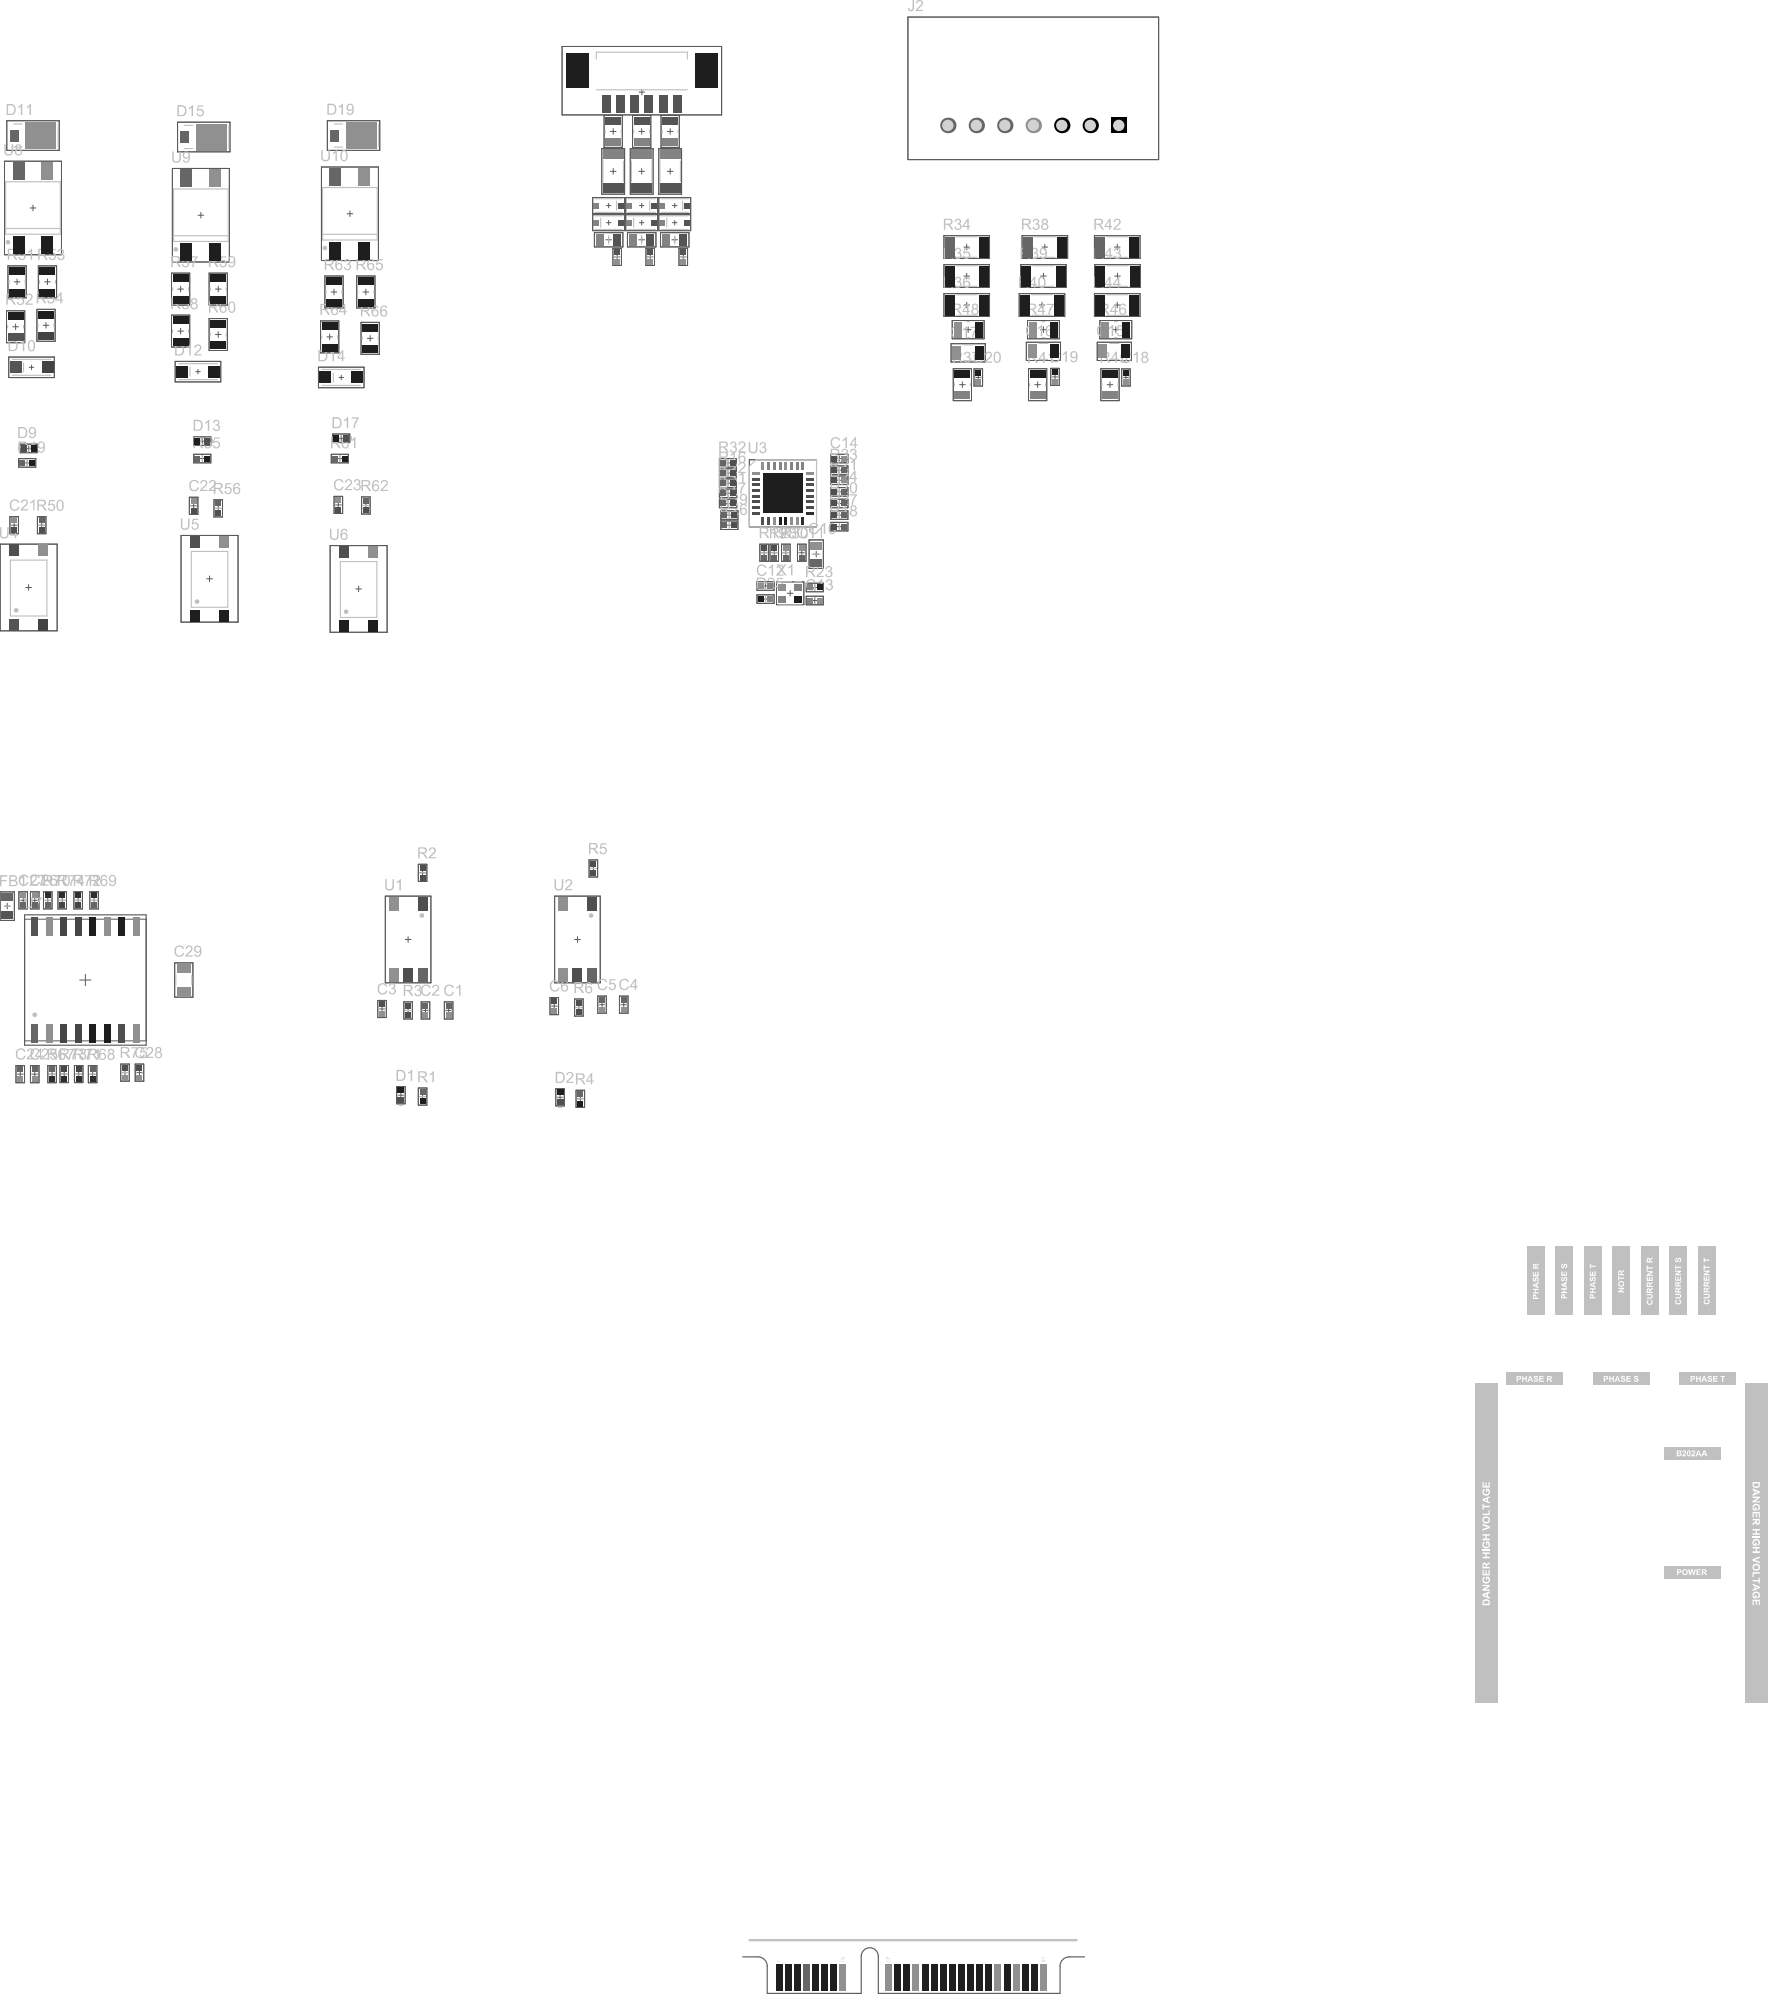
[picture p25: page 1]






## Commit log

2023-03-13 Module electronic update
    [AL1 Signal Isolation.SchDoc, AL2 Signal Isolation.SchDoc, AL4 Signal Isolation.SchDoc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]
2023-03-13 Output job update
    [B202AA-PCIe.GBL, B202AA-PCIe.GBO, B202AA-PCIe.GBP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]
2023-03-13 Initial Update
    [B202AA-PCIe.PrjPcb]
2023-03-13 Schematic link update
2023-03-21 Opto ic changed
    [AL1 Signal Isolation.SchDoc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]
2023-03-21 Silk Update
    [B202AA-PCIe.GBL, B202AA-PCIe.GBO, B202AA-PCIe.GBP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]
2025-11-06 01.00.01 Update
    [AL1 Signal Isolation.SchDoc, AL2 Signal Isolation.SchDoc, AL4 Signal Isolation.SchDoc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]
